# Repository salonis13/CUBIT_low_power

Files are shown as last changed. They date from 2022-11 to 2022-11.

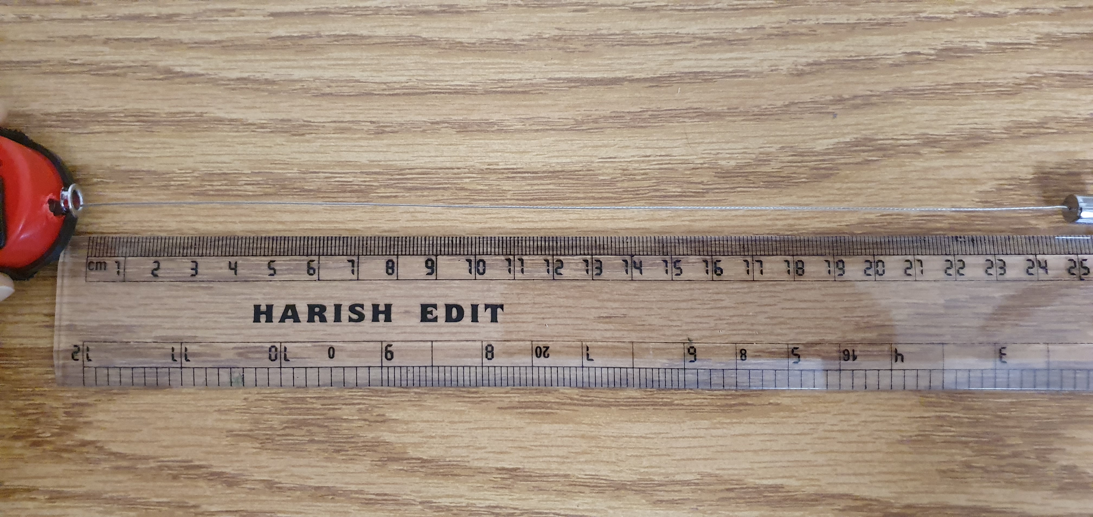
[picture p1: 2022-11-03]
images/Optical Rotary encoder 2.jpg

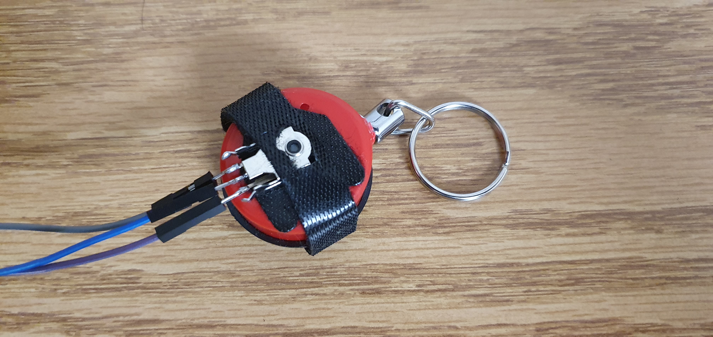
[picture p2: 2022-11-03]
images/Optical Rotary encoder 3.jpg

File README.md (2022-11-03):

# CUBIT
## ECEN5833 Low Power Embedded Firmware Development Project

Practically learn physical design techniques to develop a battery and energy harvested powered radio networked device for consumer, industrial, and high reliability applications. Through this project, we explored the engineering tradeoffs and made decisions on energy sources, energy storage devices, power supplies, radio networks, micro controllers, and sensors. Over the course of the semester, we went through design concept, design architecture, schematic entry, board layout design, PCB manufacturing, PCB assembly, test, debug, and verification.

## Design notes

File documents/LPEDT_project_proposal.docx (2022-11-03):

Project Proposal

ECEN 5833: Low Power Embedded Design Techniques

CUBIT

Smart Measuring Instrument

Team Name: Cubit

Team Members: Rajat Chaple

Saloni Shah

Background:

A measuring tape is used in a myriad of commercial businesses like construction, tailoring, warehouses as well as in day-to-day life. The first standard measuring tape was invented in 1850s and till now we have been using the same product. Although, since 18th century the world has advanced in every possible way, we still use the same measurement technique. The conventional measuring tape has ample of drawbacks like taking and maintaining measurements is very tedious, also all the measurements taken are majorly single use. It is high time that we modernize our method of taking measurements and digitize the data which can be easily stored and accessed from anywhere.

Project Summary:

For the course project, our team is designing a smart measuring instrument which will have the capability to take precise linear and angular measurements and transmit the data over to a mobile application using Bluetooth. Primarily, this device will have an encoder-wheel assembly which can be used to take measurements over a straight or curved surface very accurately. A high precision rotary encoder will be helpful in giving high resolution results. Moreover, we will also install an inertial measurement unit (IMU) sensor to take different angular and device orientation data. Both measurements can then be transmitted to a mobile app connected to the product using Bluetooth. This data will also be displayed on an LCD. This device will run on a small battery, and it will also contain an energy harvesting system using solar panel to recharge the battery. All these components will be interfaced with a single Blue Gecko board. The device will operate in low power mode by implementing load power management and utilizing minimum current for required peripherals.

108cm
0°

Measuring Tape

Wheel fixed on rotary encoder

LCD

Fig 1: Product Concept

Product Application:

- This product can be used to fulfill majority of measurement requirements like taking size data of a straight or uneven surface and taking angle measurements.
- This product can be used in small industries, construction sites, fashion companies and regular households.
- This product will eliminate the need to manually store measured data.
- This product will be low cost, low power consuming with energy harvesting mechanism.
- This product will use long lasting rechargeable batteries unlike single usage dry cells.

Block Diagram:

Micro-controller
Blue Gecko EFR32

IMU sensor

Rotary Encoder

Power Management

Battery

Solar panel-based charging

LCD Display

Product Components:

Component | | Part No. | Load Power Management
Microcontroller | Silicon Labs Blue Gecko
Radio | EFR32BG13 | | ✓
Battery | Lithium Ion/Lithium Polymer | TBD
Sensor | IMU sensor | BNO005 | ✓
| Rotary Encoder | TBD | ✓
HMI | LCD Display/Push buttons | TBD | ✓
Energy Harvesting System | Solar cells | TBD

Proposed Product Demo:

0cm
0°

Measuring Tape

36cm
0°

Measuring Tape

108cm
0°

Measuring Tape

As shown in the above image, this measuring tape can be used to measure any surface. The wheel encoder assembly installed on the product can be slid over a flat or uneven surface to get size value accurately. This measuring tape will have a high resolution in centimeter because of the use of a precision Rotary encoder with large number of pulse detection in a single rotation.

108cm
0°

Measuring Tape

108cm
30°

Measuring Tape

The above image shows how an angle measurement can be carried out using the product. This angle can be measured in any orientation of the device. The angle measurement will also be highly accurate due to the IMU sensor.

Product Features:

- Free android app to store and manage measurement data
- Bluetooth connectivity of mobile phone with the device
- Rotary encoder-wheel assembly for linear measurement
- IMU sensor for accurate angle measurement
- LCD Display for better user experience
- Energy harvesting mechanism using solar panels
- Load power management by turning on only required peripherals
- Single rechargeable LiPo battery which can power the complete device

Product Specifications:

- Dimensions: TBD
- Weight: TBD
- Wireless range: 100 m
- Size accuracy: ± 1 cm
- Angle accuracy: ± 1°
- Battery Life: TBD

Project Proposal

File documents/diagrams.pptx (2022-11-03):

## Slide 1

ESP 8266

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
MOSI

CS

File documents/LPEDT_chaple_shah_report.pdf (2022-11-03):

## ECEN 5833: Low Power Embedded Design Techniques

# CUBIT

# Smart Measuring Instrument

Team Name: | Cubit
Team Members: | Rajat Chaple
| Saloni Shah

Contents

Project Proposal

6.1.3 Actual Bulk capacitor value required (considering the DC bias)....55

7.1.1 | Testing of PWM output generation on Magnetic Encoder: | 59
7.1.2 | Frequency divider for Magnetic Encoder output: | 60
7.1.3 | Interfacing ultrasonic sensor with Blue Gecko development kit:..61
7.1.4 | Altium Board Layout: | 62
7.2 Activities planned for the upcoming week: | 63

Tables:
Table 1: Components List | 9
Table 2: Temperature specifications for sensors | 13
Table 3: Super cap - Battery comparison | 22
Table 4: Supercap and battery specifications | 22
Table 5: Voltage range for components | 23
Table 6: Components' library list | 29
Table 7: Timing Information | 32
Table 8: Battery specifications | 33
Table 9: Battery Tolerances | 33
Table 10: Project Schedule | 35

Project Proposal

## Project Proposal

## ECEN 5833: Low Power Embedded Design Techniques

# CUBIT

# Smart Measuring Instrument

Team Name: | Cubit
Team Members: | Rajat Chaple
| Saloni Shah

Project Proposal

# 1.1 Background

A measuring tape is used in a myriad of commercial businesses like construction, tailoring, warehouses as well as in day-to-day life. The first standard measuring tape was invented in 1850s and till now we have been using the same product. Although, since 18th century the world has advanced in every possible way, we still use the same measurement technique. The conventional measuring tape has ample of drawbacks like taking and maintaining measurements is very tedious, also all the measurements taken are majorly single use. It is high time that we modernize our method of taking measurements and digitize the data which can be easily stored and accessed from anywhere.

# 1.2 Project Summary

For the course project, our team is designing a smart measuring instrument which will have the capability to take precise linear and angular measurements and transmit the data over to a mobile application using Bluetooth. Primarily, this device will have an encoder-wheel assembly which can be used to take measurements over a straight or curved surface very accurately. A high precision rotary encoder will be helpful in giving high resolution results. Moreover, we will also install an inertial measurement unit (IMU) sensor to take different angular and device orientation data. Both measurements can then be transmitted to a mobile app connected to the product using Bluetooth. This data will also be displayed on an LCD. This device will run on a small battery, and it will also contain an energy harvesting system using solar panel to recharge the battery. All these components will be interfaced with a single Blue Gecko board. The device will operate in low power mode by implementing load power management and utilizing minimum current for required peripherals.

Project Proposal

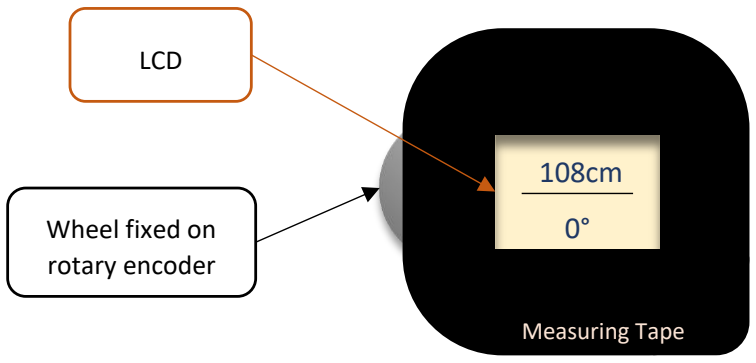
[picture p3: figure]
Measuring Tape; Wheel fixed on rotary encoder; LCD

Figure 1: Product Concept

# 1.3 Product Application

- This product can be used to fulfill majority of measurement requirements like taking size data of a straight or uneven surface and taking angle measurements.
- This product can be used in small industries, construction sites, fashion companies and regular households.
- This product will eliminate the need to manually store measured data.
- This product will be low cost, low power consuming with energy harvesting mechanism.
- This product will use long lasting rechargeable batteries unlike single usage dry cells.

Project Proposal

# 1.4 Block Diagram

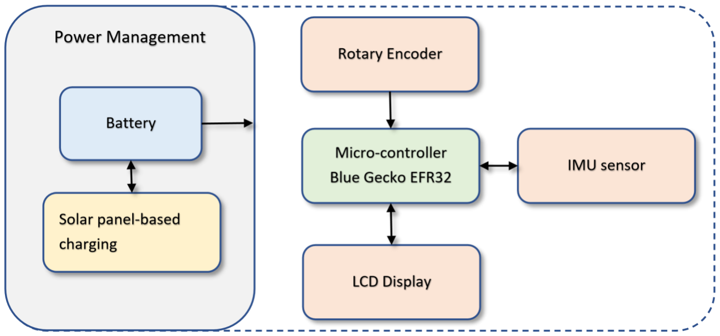
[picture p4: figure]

Figure 2: Block Diagram

# 1.5 Product Components

Table 1: Components List

Component | | Part No. | Load Power Management
Microcontroller | Silicon Labs Blue Gecko
Radio | EFR32BG13 | |
Battery | Lithium Ion/Lithium Polymer | LP802036JU+PCM+2 WIRES 50MM Jauch Quartz | Batte Products | DigiKey (https://www.digikey.com/en/products/detail/jauch-quartz/LP802036JU-PCM-2-WIRES-50MM/9560981)
PMIC | BQ25570 | BQ25570RGRT Texas Instruments | Integrated Circuits (ICs) | DigiKey (https://www.digikey.com/en/products/detail/texas-instruments/BQ25570RGRT/4430477)

Project Proposal

Buck Converter | TPS62842 Or PMIC internal buck converter | TPS62842DGRR Texas Instruments | Integrated Circuits (ICs) | DigiKey (https://www.digikey.com/en/products/detail/texas-instruments/TPS62842DGRR/12352343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)
Sensor | IMU sensor | BNO005 (To be acquired from Professor) |
| Rotary Encoder | Magnetic Rotary Encoder (https://www.digikey.com/en/products/detail/ams/AS5147P-TS-EK-AB/5452349) Magnetic Wheel Assembly (https://www.digikey.com/en/products/detail/ams/RMH05-DK-XX-1-0/3712276) |
| Ultrasonic Sensor | Adafruit Ultrasonic Sensor (https://www.digikey.com/en/products/detail/982/982-ND/5356850?itemSeq=389285645) |
HMI | LCD Display | Adafruit SHARP Memory Display Breakout - 1.3" (https://www.adafruit.com/product/3502) (Acquired from Professor) |
| Push Buttons | Available
Energy Harvesting System | Solar cells | Monocrystalline solar cells (https://www.digikey.com/en/products/detail/anysolar-ltd/KXOB25-12X1F-TB/9990434)

# 1.6 Proposed Product Demo

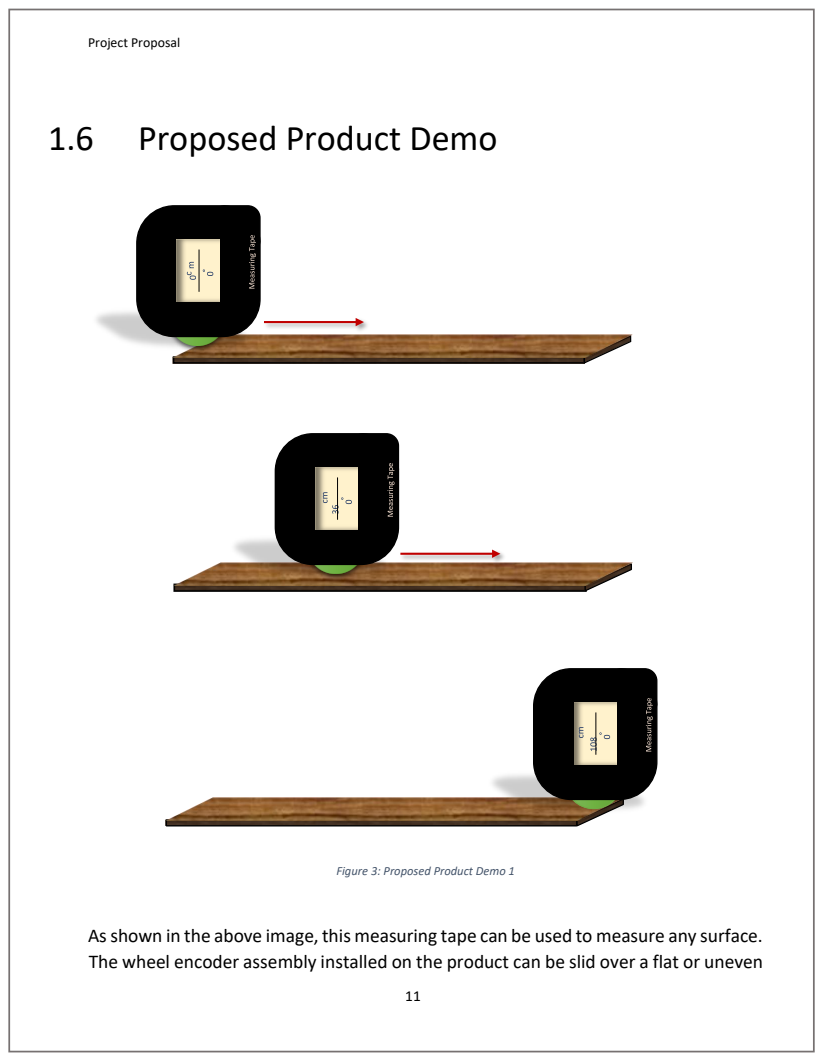
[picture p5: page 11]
Project Proposal

Figure 3: Proposed Product Demo 1

As shown in the above image, this measuring tape can be used to measure any surface.
The wheel encoder assembly installed on the product can be slid over a flat or uneven

Project Proposal

surface to get size value accurately. This measuring tape will have a high resolution in centimeter because of the use of a precision Rotary encoder with large number of pulse detection in a single rotation.

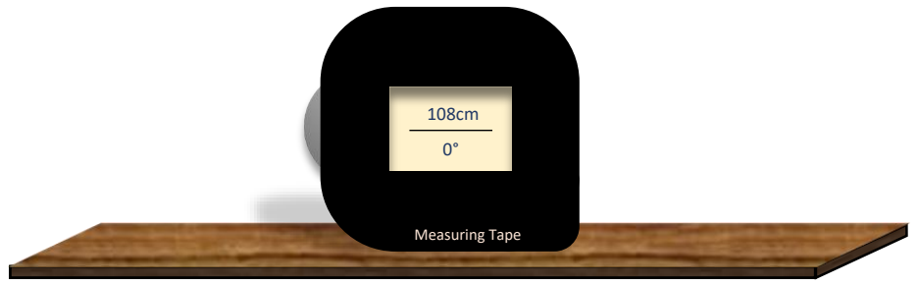
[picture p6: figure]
Measuring Tape
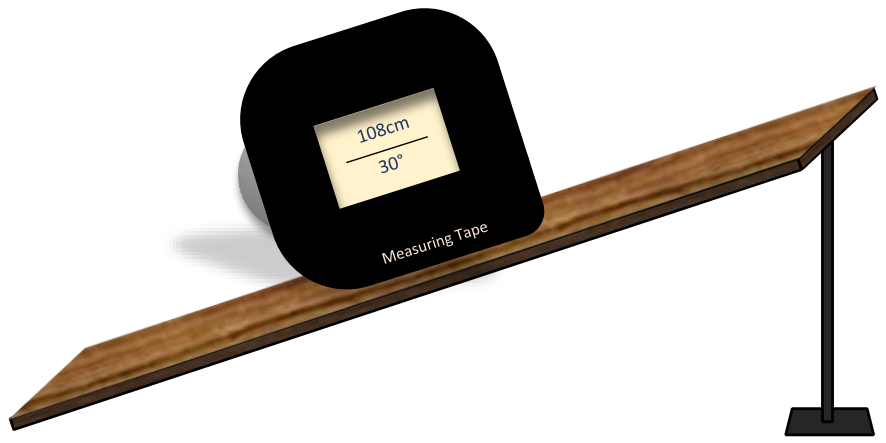
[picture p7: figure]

Figure 4: Proposed Product Demo 2

The above image shows how an angle measurement can be carried out using the product. This angle can be measured in any orientation of the device. The angle measurement will also be highly accurate due to the IMU sensor.

Project Proposal

# 1.7 Product Features

- Free android app to store and manage measurement data
- Bluetooth connectivity of mobile phone with the device
- Rotary encoder-wheel assembly for linear measurement
- IMU sensor for accurate angle measurement
- LCD Display for better user experience
- Energy harvesting mechanism using solar panels
- Load power management by turning on only required peripherals
- Single rechargeable LiPo battery which can power the complete device

# 1.8 Product Specifications

- Dimensions: 100mm x 70mm
- Weight: 100g
- Wireless range: 100 m
- Size accuracy: ± 1 cm
- Angle accuracy: ± 1°
- Product Warranty: 2 years
- Operating Temperature: 0°C - 65°C
- Internal sensors and peripheral operating temperature:

Table 2: Temperature specifications for sensors

Sensor | Operating Temperature Constraints
Blue Gecko | -40 to 85 °C
IMU | -40 to 85 °C
Rotary encoder | -40 to 150 °C
LCD Display | -40 to 70 °C

Project Update #2

## 2 Project Update 2 ECEN 5833: Low Power Embedded Design Techniques

# CUBIT

# Smart Measuring Instrument

Team Name: | Cubit
Team Members: | Rajat Chaple
| Saloni Shah
Date: | 01/29/2022

# 2.1Activities accomplished in past week

- Studied mouse scroll-wheel encoder assemblies to decide the decide the mechanical assembly for final product. Disassembled 4 different optical mouses to explore different assemblies.

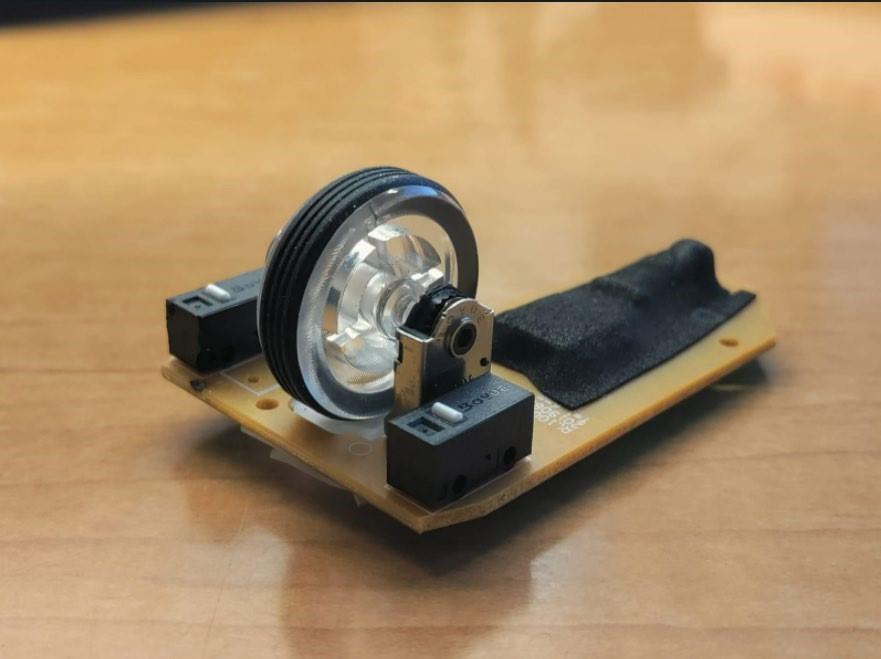
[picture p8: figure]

Figure 5: Scroll wheel encoder assembly

- Measured PPR(Pulse per rotation) of rotary encoder and circumference of wheel to estimate linear measurement resolution. o Finalized ultra-low power Graphic LCD display. o Estimated total power and energy consumption of the product.
- Worked on project planning and estimated timeline.
2.2 Activities for the coming week • Finalize battery and solar panel based on energy consumption requirements. o Finalize Power management IC. • Work on power supply circuit for the product.

# 2.3 Energy model for the product:

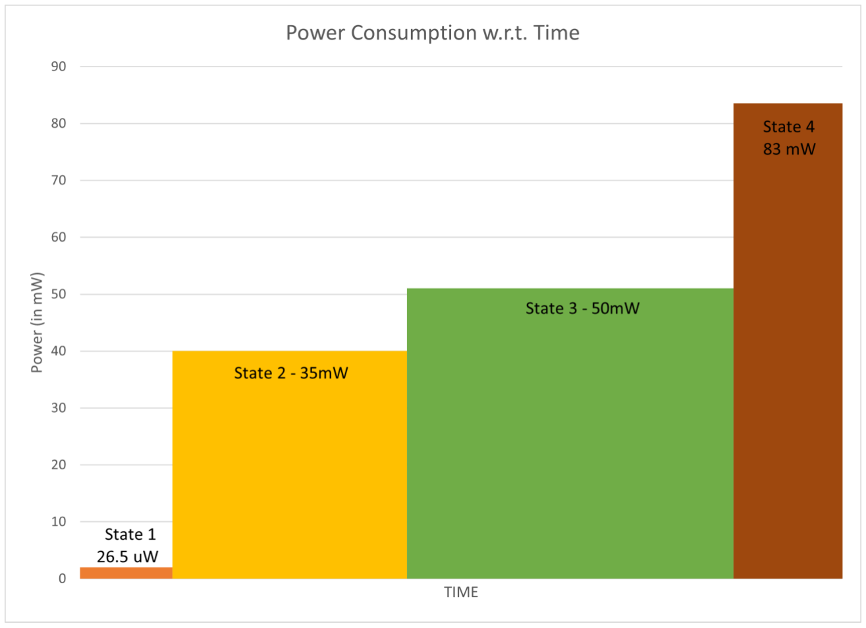
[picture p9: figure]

Figure 6: Energy model

# 2.4 Sensor selection:

### 2.4.1 IMU Sensor: BNO005

- This sensor works on I2C as well as UART.
- We will be interfacing the sensor using I2C as data transfer over UART communication takes longer and even though it consumes less energy, overall efficiency of UART decreases. Moreover, for transfer of larger data bytes I2C consumes the same amount of energy. (These assumptions were made using this reference. (http://cc.oulu.fi/~kmikhayl/site-assets/pdfs/2012_NTMS.pdf)) (http://cc.oulu.fi/~kmikhayl/site-assets/pdfs/2012_NTMS.pdf)
- This sensor will require external load switch as after start-up it only enters low power mode and suspend mode. (Even in suspend mode it consumes 40uA of current).

### 2.4.2 Rotary encoder

- This mechanical encoder has just 2 digital pins which can be wired directly as input to the controller. The encoder generated pulses gives the angular position of the axis and can then be converted to digital output.
- The encoder will also require external load switch as it does not have internal circuitry to turn power off.

Online Project Management using Monday.com (https://view.monday.com/2210043877-dee7e4668b7b619c0c4a18486899a087?r=use1)

# 2.5 Program Flowchart:

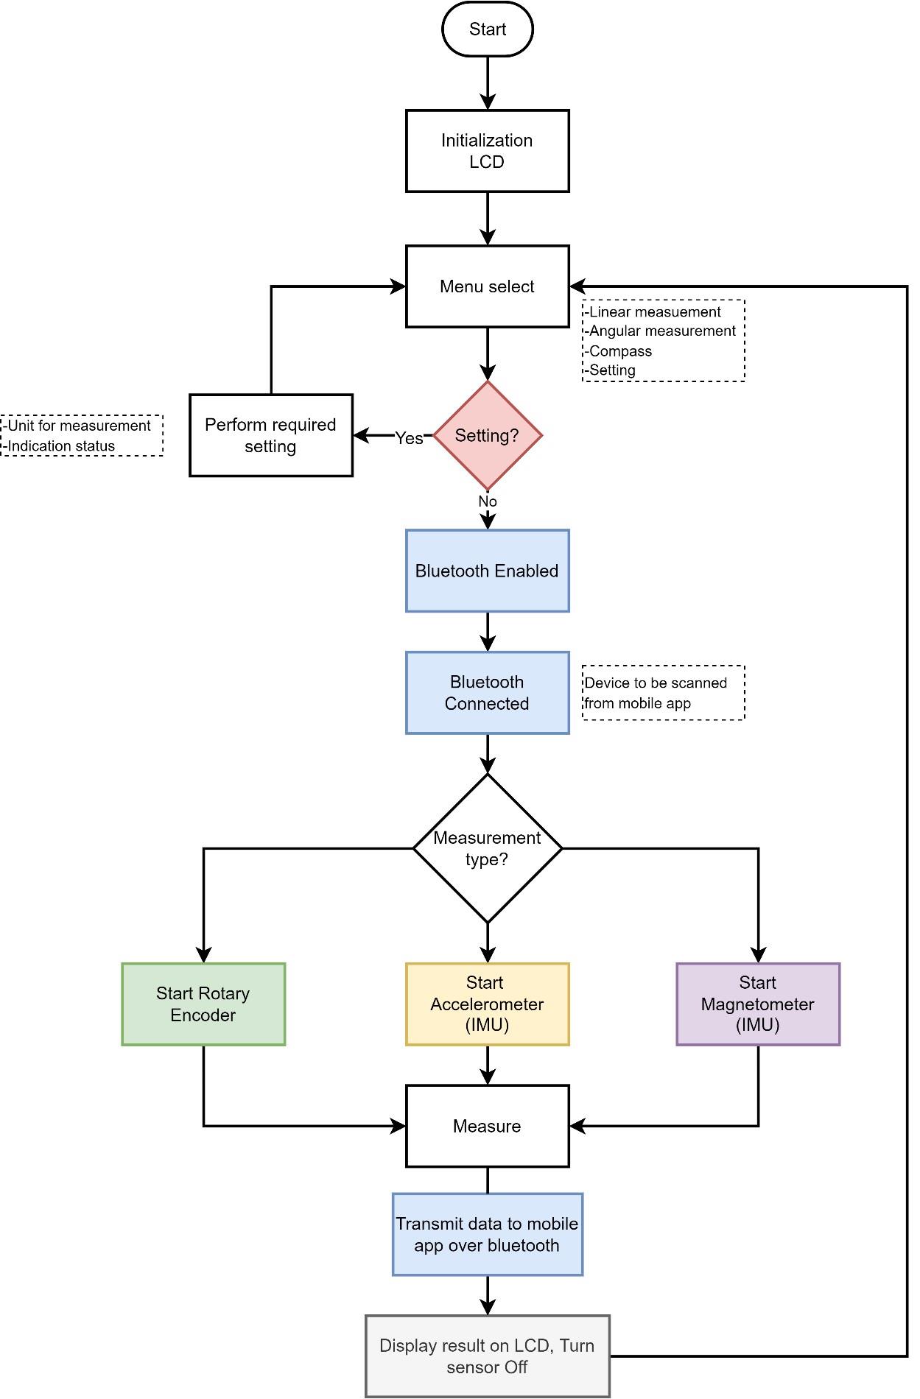
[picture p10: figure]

Figure 7: Flowchart

## 3 Project Update 3 ECEN 5833: Low Power Embedded Design Techniques

# CUBIT

# Smart Measuring Instrument

Team Name: | Cubit
Team Members: | Rajat Chaple
| Saloni Shah
Date: | 02/05/2022

# 3.1 Activities accomplished in past week:

- Finalized energy storage element (battery) based on energy consumption requirements.
- Finalized Power management IC and buck-converter IC.
- Practically implemented measurement system using mechanical rotary encoder, string-pulley assembly and interfaced it with Arduino. Found out that the rotary encoders have a limitation on how fast it can detect rotations i.e. it can only detect signals correctly at less than 160 rpm.

Figure 8: Assembled rotary encoder with a string-pulley

Figure 9: Measuring the length of a ruler using the assembly

Arduino serial monitor output with number of pulse counts and calculated length

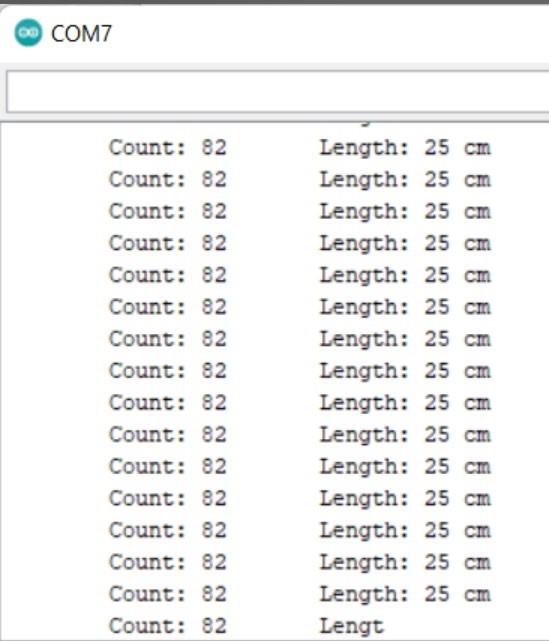
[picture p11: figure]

Figure 10: Optical Rotary Encoder output

- Changed the required rotary encoder from mechanical to magnetic due to speed constraints and higher chances of signal misses in the mechanical encoder.
- Finalized required magnetic rotary encoder and ultrasonic sensor for measurement applications.

# 3.2 Activities for the coming week

- Finalized energy harvesting element (solar panel) based on energy consumption requirements.
- Design product power supply circuit.
- Interface LCD display with Blue Gecko Evaluation Module.
- Finalize other required components for the product schematic design.

Power Storage Element Selection
- Expected runtime using supercapacitor = 1.36 hours
- Expected runtime using battery = 3 days (8 hours per day)¹

### 3.2.1 Super Cap vs Battery

Required peak current: 25 mA
Average current consumption: 13.68 mA
Average Charge requirement for continuous 8 hours operation: 110mAh Average Energy Required for 8 hours of operation: 328.4 uWh
Ambient Temperature Conditions: Room Temperature (about 25° C)

Table 3: Super cap - Battery comparison

Super Cap | Battery
Steep discharge curve | Higher operating time
Large leakage current (30 uA) | Very less leakage current (2%/year)
Cannot handle required peak current | Can handle upto 1A peak current
Lower energy density | Higher energy density
Can operate in very low temperature | Dispenses less energy in low temperatures
Lower ESR power loss | Higher ESR power loss

Table 4: Supercap and battery specifications

Design Requirements | Super Cap (Tecate 100F) | Battery (Jauch 480mAh)
Useable Energy | 234.5J² - 18.6mAh | 480 mAh
Peak Discharge Current | | 1A
Recharge time | | 2 hours @ 0.5C
2 years of use, 300 charges | 500,000 cycles | 300 cycles ~ 80% capacity usage
Leakage current or rate | 3 uA | Less than 2-3%
ESR | 210 mΩ
Mechanical Dimensions | 12.5 x 25 mm | 38 x 20.5 mm

1 Refer attached spreadsheet for calculations 2 Refer attached spreadsheet

# 3.3 Power Management Unit Selection

### 3.3.1 Determining the required voltage range for the product

- To decide the operating voltage range for the product, we looked at the input voltage range of the peripherals utilized in the system. The below table shows the minimum and maximum input voltage range of the sensors and MCU.

Table 5: Voltage range for components¹

Sensor | Vin(min) | Vin(max) | Current Consumption
Blue Gecko | 1.8V | 3.8V | 4uA
IMU | 2.4V | 3.6V | 12.3mA
Rotary encoder | 3V | 3.6V | 15mA
LCD Display | 3V | 5V | 4uA
- Based on the above calculations, we decided to operate all the peripherals at 3.0V as to utilize maximum possible battery capacity and increase the operating time of the system.
- The approximate range of the supply voltage will be from 3.0-3.6V.

1
IMU datasheet: BNO055 Datasheet (mouser.com) (https://www.mouser.com/datasheet/2/783/BST_BNO055_DS000-1509603.pdf)
Blue Gecko datasheet: (https://www.silabs.com/documents/public/data-sheets/efr32bg13-datasheet.pdf) EFR32BG13 Data Sheet: Blue Gecko Bluetooth® Low Energy SoC Family (silabs.com) (https://www.silabs.com/documents/public/data-sheets/efr32bg13-datasheet.pdf)
Magnetic Rotary Encoder datasheet: (https://www.digikey.com/en/products/detail/ams/AS5147P-TS-EK-AB/5452349) AS5147P-TS_EK_AB ams | Development Boards, Kits, Programmers | DigiKey (https://www.digikey.com/en/products/detail/ams/AS5147P-TS-EK-AB/5452349) LCD (https://www.digikey.com/en/products/detail/ams/AS5147P-TS-EK-AB/5452349)
Display datasheet: (https://cdn-shop.adafruit.com/product-files/3502/Data+sheet.pdf) Data+sheet.pdf (adafruit.com) (https://cdn-shop.adafruit.com/product-files/3502/Data+sheet.pdf)

### 3.3.2 Determining the power management topology

- Considering that the power source battery gives maximum 3.7V and our required voltage supply for the peripherals is about 3.0V, which is always lower than supply voltage we decided to implement a buck converter to meet our power requirements.
- The primary reason for choosing a buck converter as opposed to a buck-boost is that most Lithium-Poly batteries have a plateau from 3.5-3.6V and very little charge below this plateau, limiting the usefulness of the buck-boost converter and its wide input voltage range2.
- Moreover, the buck-boost converter also has one additional MOSFET as compared to the buck converter which increases power loss and decreases efficiency of the converter.
- Keeping this in mind, we searched for a buck converter IC, with high efficiency, low quiescent current, low cost, and smaller footprint.
- All these requirements were successfully met by the buck converter TPS62840³

### 3.3.3 Determining Regulated or Unregulated Power Source

- While deciding whether to use regulated or unregulated power source, we carried out following calculations to understand efficiency of both topologies.

Assumed product usage of 60 minutes or 3600 seconds

Assumed number of measurements in 1 hour, average of 20 measurements

Assumed period for one measurement, average of 13 seconds

On duty cycle = (20 measurements * 13 seconds) / 3600 = 7.2% Off

duty cycle = 92.8%

2 EETimes - Buck-boost vs. buck converter: it's about battery life in portables (https://www.eetimes.com/buck-boost-vs-buck-converter-its-about-battery-life-in-portables/)
3 TPS62840 datasheet: (https://www.ti.com/lit/ds/symlink/tps62840.pdf?HQS=dis-dk-null-digikeymode-dsf-pf-null-wwe&ts=1644076764086) TPS62840 1.8-V to 6.5-V, 750-mA, 60-nA IQ Step-Down Converter datasheet (Rev. D) (ti.com) (https://www.ti.com/lit/ds/symlink/tps62840.pdf?HQS=dis-dk-null-digikeymode-dsf-pf-null-wwe&ts=1644076764086)

TPS62840 Buck converter Efficiency Curve

- Off duty cycle = 0.015-0.020 mA Estimated 87.5% efficiency
- On duty cycle = 15-20 mA range Estimated 94% efficiency

For regulated power case (using TPS62840 buck converter):

- On duty cycle
- TPS62840 efficiency ~3.6V input and 15,500uA is 94% + 0.06uA Iccq
- Weighted avg power OOB = (On duty cycle * (15500 + 0.06) * 3.0V) / 94%
- Weighted average power out of battery = 3561 uW o Off duty cycle
- TPS62840 efficiency ~3.6V input and 20uA is 87.5% + 0.06uA Iccq

- Weighted avg power OOB = (Off duty cycle * (20 + 0.06) * 3.0V) / 87.5%
- Weighted average power out of battery = 63.8 uW o Total Average Power out
- Weighted on duty cycle average power + Weighted off duty cycle average power = 3561uW + 63.8uW = 3624.825 uW

For unregulated power case (using Blue Gecko internal LDO):

- On duty cycle
- Gecko efficiency ~3.6V input and 15,500uA is 83.33%
- Weighted average power OOB = (On duty cycle * 15500 * 3.0V) / 83.33%
- Weighted average power out of battery = 4017.7 uW o Off duty cycle
- Gecko efficiency ~3.6V input and 20uA is 83.33%
- Weighted average power OOB = (Off duty cycle * 20 * 3.0V) / 83.33%
- Weighted average power out of battery = 66.81 uW o Total Average Power out
- Weighted on duty cycle average power + Weighted off duty cycle average power = 4017.7uW + 66.81uW = 4084.5 uW

Increase in battery life using regulated power = 1 -

= 11.25%

Based on above calculations, we decided to use a regulated power source since it provides longer battery life. Moreover, we have a higher on duty cycle, higher power on to power off ratio, higher efficiency at light load and low quiescent current which justifies the use of regulated power source.

### 3.4. Determining the Power Management IC

- The primary criteria for selecting a PMIC were low minimum input voltage limit to support very low voltage from energy harvesting element (solar cell) and efficient boost converter. A simple and efficient circuitry for energy harvester is required which were available in PMIC BQ25570.

- The input voltage supported in this IC is 0.1-5.1V. Also, many typical solar cells have an output voltage of 0.1V.
- Another important criterion is to have a wide range of input voltage from battery to support lower battery power which is 2-5.5V in case of BQ25570.
- This IC also has higher charging current capacity (maximum 285mA) for fast charging from external charger or a USB charging port.
- BQ25570 also has internal Programmable Maximum Power Point Tracking (MPPT) circuitry for optimal energy extraction from energy harvester like solar panel.
- Moreover, BQ25570 has internal boost as well as buck converter to boost low input voltage from the energy harvester and simultaneously regulate the output voltage⁴

4 BQ25570 internal buck converter vs external TPS62840 buck converter: The TPS62840 buck converter has higher efficiency at low current consumption than the internal buck converter.

## 4 Project Update 4 ECEN 5833: Low Power Embedded Design Techniques

# CUBIT

# Smart Measuring Instrument

Team Name: | Cubit
Team Members: | Rajat Chaple
| Saloni Shah
Date: | 02/12/2022

# 4.1Activities accomplished in past week:

- Generated Altium components library for following parts

Table 6: Components' library list

Sr. No | Part Description | Part Number | Footprint Name | Online SnapEDA/ Octopart Link
1 | Blue Gecko | EFR32BG13P732F512GM48-D | 48-QFN_7x7 | N/A
2 | PMIC | BQ25570RGRT | 21_QFN_35X35 | N/A
3 | IMU Sensor | BNO055 | LGA28R50P4X10_380X520X100 | BNO055 SnapEDA (https://www.snapeda.com/parts/BNO055/Bosch%20Sensortec/view-part/)
4 | Magnetic Encoder | AS5147P-HTSM | 14-TSOP_5x4_4 | N/A
5 | Resistor | RMCF0603FT1K00 | 2_Chip_0603_RMCF | N/A
6 | Capacitor | CL10A475KP8NNNC | CAP_0603_1MM | N/A
7 | Inductor | VLS3015CX-220M-1 | 2_IND_3x3 | N/A
8 | LED (red) | 150060RS75000 | LED_0603_RED_WL-SMCW | N/A
9 | LCD header | 3502 | LCD_SHARP_MEMORY_9_PIN | N/A

### 4.1.1 Change in the Power management strategy

- With earlier update, plan was to use PMIC bq25570 and TPS62842 buck converter. Criterion for selection of external buck converter instead of one already integrated into bq25570 was Efficiency. However, considering ON duty cycle of the product operation, efficiency would no longer be a preliminary factor under consideration.
- Also, major concern where we cannot utilize most energy from the battery was resolved using following.
- Entire circuit would work at 3.15v
- Buck converters have dropout voltage. This limits battery’s minimum usable voltage. As per datasheet, dropout voltage is maximum output current times the buck high side resistance.

- Usable battery would be in the range of 3.7v down to 3.22v.

### 4.1.2 Tested battery power consumption from a sample project

- As a case study one of the sample projects was arranged. Though this project’s objective is entirely different than that of CUBIT, similarities in functional blocks were identified. This project also contains solar energy harvesting, PMIC and a load.

Figure 11: Sample Product for case study

Calculations:
Maximum output current: 35 mA Maximum buck high side resistance: 200Ω

Dropout voltage: 35 x 200 = 0.7v

Energy
Harvesting unit

Load
(Power LED)

Battery
(300 mAh)

### Sample Project Block Diagram

Calculations:

Continuous current consumption by Power LED = 55 mA

Tℎeoretical battery backup =

Battery capacityሺmAℎሻ
Continuous current consumption

=

500
55 = 9.09 Hrs

Objective: Solar power lamp
Battery capacity = 500mAh
No of Solar cells = 7 (part number unknown)
LEDs: 1 power LED of typical current consumption of 50mA
Solar Panel | Microcontroller | LED Driver
Battery | LED

Practically measured battery backup: 9 hours
If current consumption was 18mA, we would get battery backup of ~27 Hrs

Outcome of the experiment:
Our calculation for CUBIT falls between this range where battery backup for 480 mh battery with 18mA avg current consumption is around 24 Hrs. This verifies calculations against practical measurements.

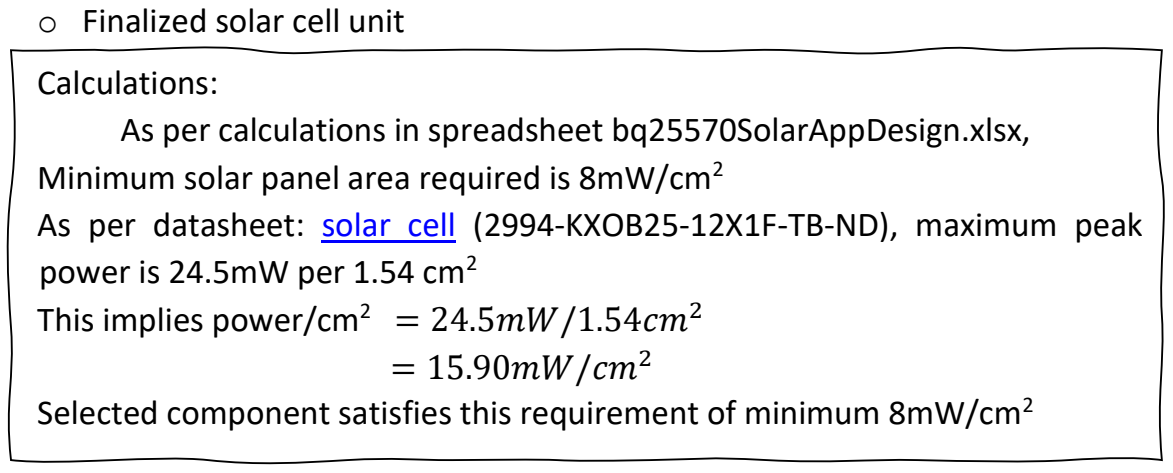
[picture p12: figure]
• Finalized solar cell unit; Calculations:; power is 24.5mW per 1.54 cm² This implies power/cm²; = 24.5mW/1.54cm² = 15.90mW/cm²

### 4.1.3 Version tracking using GitHub

Updated previous updates, libraries and calculation documents to github rajatchaple/ecen5833_s22_lpedt_project (github.com) (https://github.com/rajatchaple/ecen5833_s22_lpedt_project)

### 4.1.4 Timing information

Following are the critical timing parameters per module.

Table 7: Timing Information
Device | Parameter | Description | Min | Max
AS5147 (SPI) | tL | Time between CSn falling edge and CLK rising edge | 350 ns
| tH | Time between last falling edge of CLK and rising edge of CSn | 50 ns
| tMOSI | Data input valid to falling clock edge
BNO055 | fSCL | Clock frequency | | 400kHz
| fSUDAT | SDA Setup Time | 0.1 us
| HDDAT | SDA Hold TIme | 0 us
SHARP Memory LCD | fSCLK | Clock Frequency | | 1.1MHz
| tsSCS | SCS Setup time | 6 us
| thSCS | SCS hold time | 2 us
| tsSI | SI setup time | 250 ns
| thSI | SI hold time | 350 ns

As per calculations in spreadsheet bq25570SolarAppDesign.xlsx, Minimum solar panel area required is 8mW/cm²
As per datasheet: solar cell (https://waf-e.dubudisk.com/anysolar.dubuplus.com/techsupport@anysolar.biz/O18Adzn/DubuDisk/www/Gen2/KXOB25-12X1F%20DATA%20SHEET%20202007.pdf) (2994-KXOB25-12X1F-TB-ND), maximum peak

Selected component satisfies this requirement of minimum 8mW/cm²

### 4.1.5 Calculations for PMIC IC

- Studied reference design in bq25570 user guide (https://www.ti.com/lit/ug/sluuaa7a/sluuaa7a.pdf?ts=1644694996855) in order to understand PMIC circuitry for our application.
- Also, used calculator provided by TI on BQ25570 data sheet, product
information and support | TI.com (https://www.ti.com/product/BQ25570#design-tools-simulation) to calculate Resistor values.

### 4.1.6 Battery specifications

Table 8: Battery specifications
Parameter | Value
Battery nominal Voltage | 3.7V
Typical capacity | 500mAh
Minimum capacity | 480mAh
Charge voltage | 4.2V
Standard current | 0.2C-100 mA
Max charging current | 0.5C – 250mA
Cut-off voltage | 3V
Max discharging current | 2C-1A
Power rating | 1.78Wh

Battery Tolerances

Table 9: Battery Tolerances
Parameter | Value
Overcharge voltage | 4.28 V ± 0.025 V
Overdischarge voltage | 3.00 V ± 0.05 V
Over current range | 1.0A to 4.0A
Charging operating temperature | +10°C to +45°C
Discharging operating temperature | -20°C to +25°C

### 4.1.7 High risk elements:

- Magnetic interference of two sensors
- IMU has a magnetometer which is to be used for compass and the rotary encoder is also based on magnetic pulse. These two components can interfere with each other and show incorrect reading. As a measure to mitigate this risk, we will be placing the two components physically as far as possible from each other on the board.
- EMI interference
- Similar to the issue mentioned, the magnetic field from these components can also generate electromagnetic interference which can disrupt the functionality of other components on the board especially inverted F-antenna for Bluetooth connection (radio frequency can be disrupted due to electromagnetic interference). The potential solutions to overcome EMI are filtering, shielding, or grounding.
- Dual charging system (USB and Solar cell)
- As a power storage component, we are using a rechargeable LiPo battery. To recharge this battery, we are planning on using energy harvesting component - solar cells. Apart from the solar cells, we also intend to have a 5V USB charging port on the board.
- The major drawback in this design is the unavailability of a power management IC to efficiently switch between solar cells and USB port. Even if we interface a USB port, we have to have a circuit design such that reverse current does not flow from battery to our energy harvesting device and also to automatically switch between solar energy and USB input.
- In this circuit design, we plan to use Schottky diodes for fast switching and low voltage drop. In case we are unable to successfully implement this design, we will be eliminating use of USB charging port and use the solar power as our primary recharge source.

### 4.1.8 Project Schedule:

Table 10: Project Schedule
Task | Deadline
Altium Components Libraries | Feb 12, 2022
Altium Product Schematic | Feb 26, 2022
Altium Product Layout | March 5, 2022
Product Final Layout for Fabrication | March 12, 2022
Send PCCB board for fabrication | March 19, 2022

We are aligned with our project timelines except the task where our plan was to bring up LCD module last week. We will be achieving this task in upcoming week. Instead, this week we focused on our case study of sample project to verify our energy calculations.

# 4.2 Activities planned for the upcoming week:

- Finalizing Bulk capacitance
- Implement LCD driver
- Schematic of Power Management Unit

## 5 Project Update 5 ECEN 5833: Low Power Embedded Design Techniques

# CUBIT

# Smart Measuring Instrument

Team Name: | Cubit
Team Members: | Saloni Shah
| Rajat Chaple
Date: | 02/18/2022

# 5.1Activities accomplished in past week:

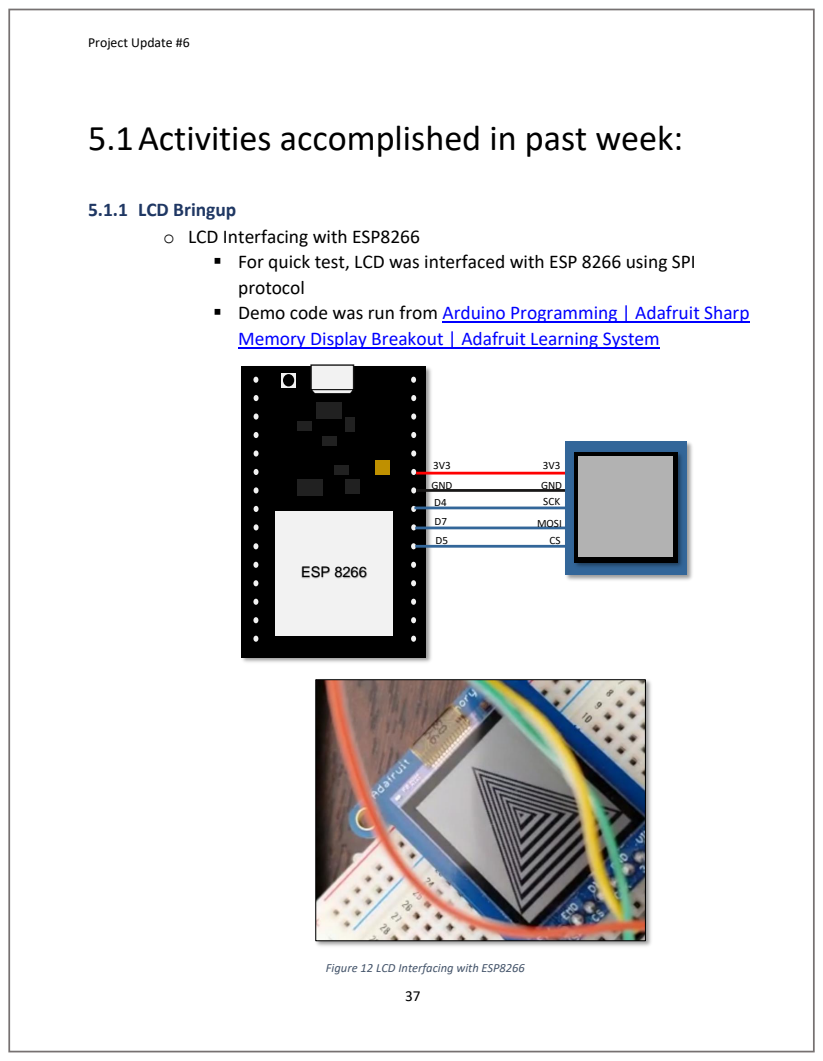
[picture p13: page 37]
5.1.1 LCD Bringup; ESP 8266; GND; SCK; MOSI

• LCD Interfacing with ESP8266
▪ For quick test, LCD was interfaced with ESP 8266 using SPI
protocol
▪ Demo code was run from Arduino Programming | Adafruit Sharp
Memory Display Breakout | Adafruit Learning System (https://learn.adafruit.com/adafruit-sharp-memory-display-breakout/programming)

Figure 12 LCD Interfacing with ESP8266

- LCD Interfacing with Blue Gecko
- Connections

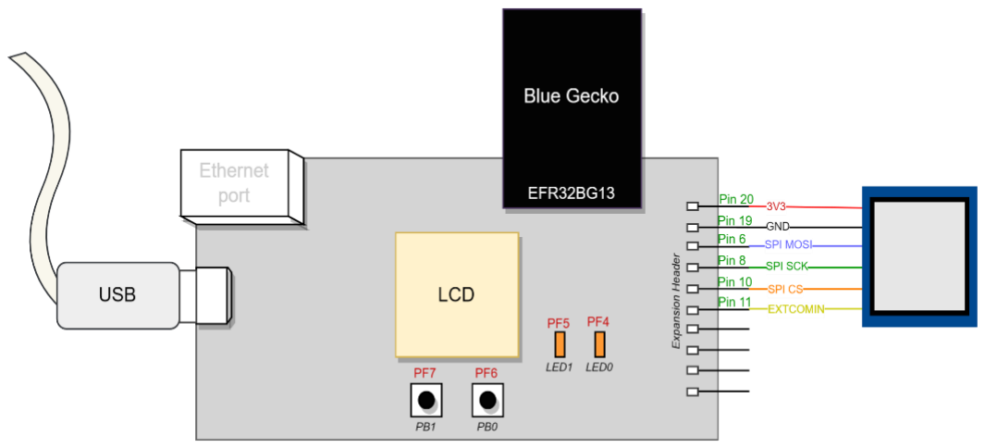
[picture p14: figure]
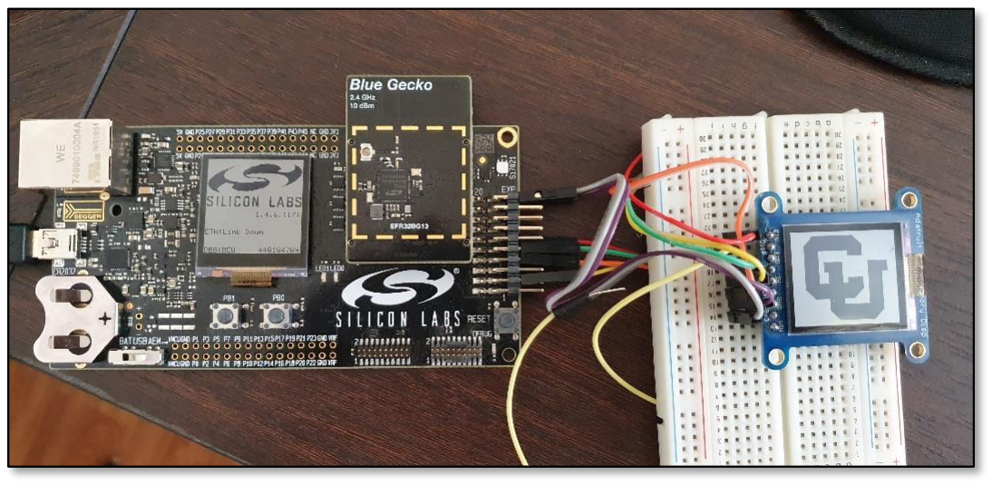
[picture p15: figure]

Figure 13 LCD Interfacing with Blue Gecko

- Python Script for Image to binary
- LCD requires array in binary format representing the graphics
- Python script was written to convert any image into 168x144 graphics.
- CU Logo was generated using this script.

- Findings

Figure 14 Current consumption by LCD
- Current consumed by LCD is around 100uA
- Getting rid of additional components from the module

Figure 15 LCD without a breakout module circuit
Current consumption did not change even after removing these additional components

LCD connected:
Current (240 uA) | LCD detached:
| Current (141 uA)

Removed Regulator and Logic level shifter

### 5.1.2 PMIC Simulation and Bulk capacitance

- In order to simulate Power management unit in LTSpice, we did not find the exact part number
- Combination of boost circuitry and LT8604 was used to simulate as these parts were matching with bq25570 specs.

Figure 16 Calculating Bulk capacitor value

Below simulation showed that there is need of 100uF bulk capacitor.

Addition of bulk capacitor restricts minimum voltage of the system at 3.15v. This satisfies requirements for all peripherals and the controller.

# 5.2Activities planned for the upcoming week:

- Designing a schematic of Power Management unit and sensor interfacing
- Implement IMU sensor driver

# 5.3Miscellaneous:

1. What features, components, will need to be added to your schematic to enable programming of your micro controller or SoC?
a. 10 pin Debug connector would be added to the board schematic

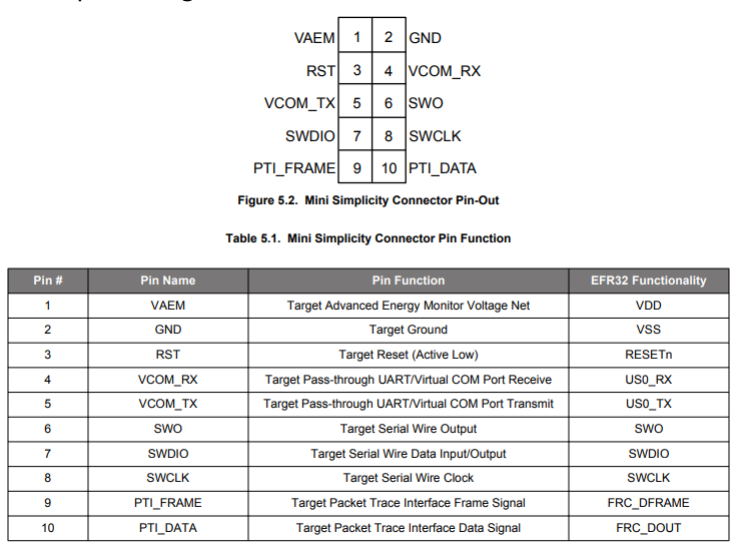
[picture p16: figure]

Figure 17 Debug connector pinout

Source: AN958: Debugging and Programming Interfaces for Custom Designs (silabs.com) (https://www.silabs.com/documents/public/application-notes/an958-mcu-stk-wstk-guide.pdf)

Following features would be available with this debug port:
1) SWD (Serial Wire Debug)
2) AEM (Advanced Energy Monitoring)
3) PTI (Packet trace interface)
4) VCOM (Virtual COM port)
5) Virtual UART

The Debug In mode of the debugging would be used

Figure 18 Debug interface with Radio board

Source: UG279: EFR32BG13 Blue Gecko Bluetooth Starter Kit User's Guide (silabs.com) (https://www.silabs.com/documents/public/user-guides/ug279-brd4104a-user-guide.pdf)

2. Describe the process of how you will compile and download code to your board, the target board
1) Simplicity studio v5 would be used as a programming IDE during development.
a. GNU ARM C compiler (cross compiler: arm-none-eabi-gcc) would be used to compile the code
b. Simplicity Studio v5 also provides an option to select your development board. This in turn defines the memory map of the controller.
2) Simplicity Commander would be used to download the code into target board Command line syntax: commander [command] [options] [arguments] Sequence of commands would be,
a. Erase Flash
b. Flash new code
c. Verify written data
d. Reset the microcontroller

3. Which signals will have test points?
a. SPI port (For LCD and Magnetic Rotary Encoder)
- SCLK
- CS
- MOSI
b. I2C port (for IMU Sensor)
- SCL
- SDA
c. UART pins (for Ultrasonic sensor)
- RX/TX
d. Power pins of each sensor
e. PMIC Vout
f. Energy Harvester Input
g. USB Input
h. Battery Storage input
4. Reset Circuit Description
Reset would be controlled by 2 modes of operation
a. Reset via Debugging Interface
- Pin 3 on Mini debug connector
b. On board reset switch
- Pin 12 on EFR32BG13 is nReset
- Active low
- It’s only required to drive this pin low externally
- Internal pull-up pulls this pin high

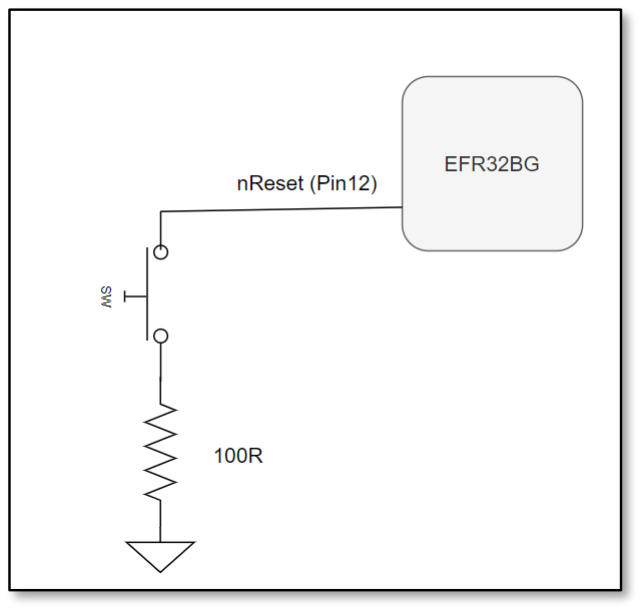
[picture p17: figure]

Figure 19 Reset circuit
5. Clock Generation Description
a. Both oscillators Low Frequency and High Frequency oscillators would be required:
- High Frequency crystal (38 to 40 MHz): For Radio
- Low Frequency crystal (32.768 kHz): For Low Energy modes operation
b. There are also other oscillators available for clock generation namely
1) High Frequency RC oscillator
2) Auxiliary high frequency RC oscillator
3) Precision LF RC oscillator
4) Low frequency RC oscillator
5) Ultra-low frequency RC oscillator

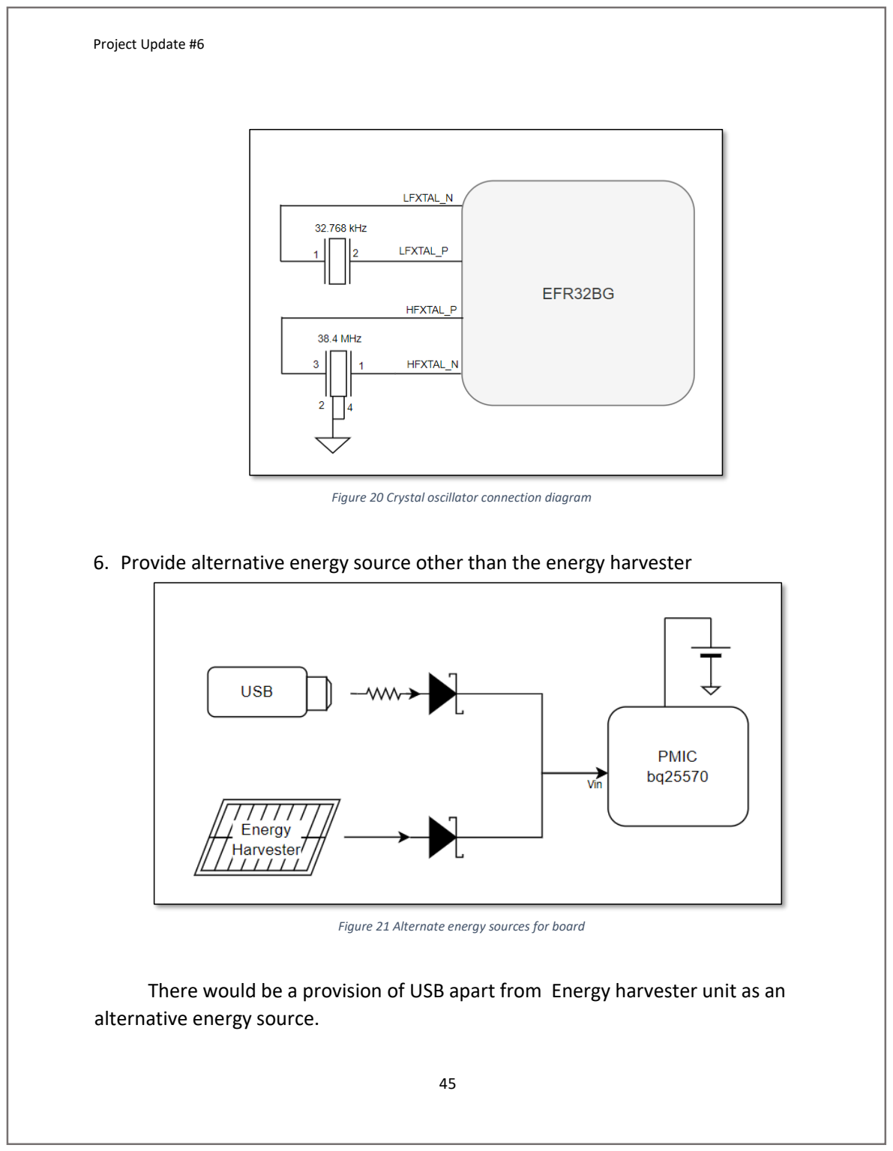
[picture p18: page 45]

Figure 20 Crystal oscillator connection diagram

6. Provide alternative energy source other than the energy harvester

Figure 21 Alternate energy sources for board

There would be a provision of USB apart from Energy harvester unit as an alternative energy source.

- Schottky diodes would be used to allow both the energy sources to be connected at the same time.
- As VIN_DC is ppulled to ground through a small resistance, USB supply would have a resistance in series to limit the current flow. This solves below problem,
7. Jump Start method to charge the energy storage element in the event that the Energy Harvester circuity is not functional or takes too long.
- Along with above circuit, there would be a provision to disconnect the battery from the embedded device and charge it using Lab power supply.
- Battery would be charged at 235mA as 250 mA is the maximum charging current for the battery. Charge voltage would be set to 4.2V

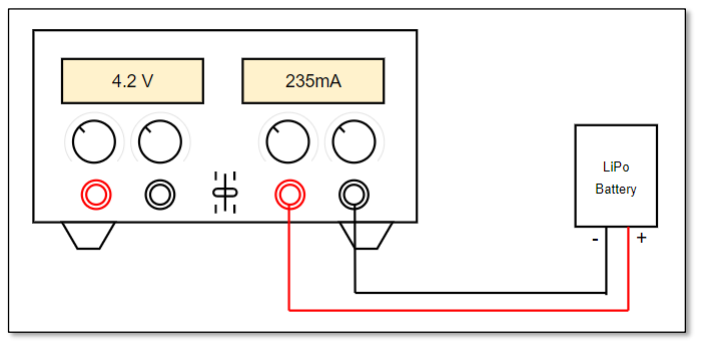
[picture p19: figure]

Figure 22 Battery charging using power supply

8. What is the maximum charging current allowed by the PMU circuitry? As per PMIC datasheet,
- Typical charging current is 235mA and
- Maximum charging current allowed by PMU is 285mA
9. What is the maximum charging current allowed by the energy storage unit specs?
- Max charge current for the battery (https://www.jauch.com/downloadfile/5bf529c4ea71fa4bbc13432e4fc07e5a8/480mah_-_lp802036ju_1s1p_2_wire_50mm.pdf) is 0.5C i.e. 250mA
10. What will the maximum current of the jump start power source be set to?
- Maximum current for the jump start can be set to 250mA as supported by the battery.
11. Where will the jump start power and ground signals connect to? Following are the two options for the jump start,
1) Disconnect battery and charge it using Lab power supply
2) Charge battery using USB via PMIC
12. Ensuring that there is enough energy / current to program the flash of the MCU how much current will the programming of the MCU flash require?
As per datasheet,
- Current consumption during flash write is 3.5 mA and
- Current consumption during Flash read is 2.0 mA

Figure 23 Flash memory specs

13. How much current will the energy storage element and the PMU be able to provide?
Unit | Current
Energy storage element (Battery) | 1 A (2C)
PMU (bq25570) | 110 mA
14. What are the connection points to enable external power to digital / MCU portion of the board?
- USB as an input to the PMIC would be used to power digital/MCU portion of the board.
- External lab power supply would be used to charge the battery.

## 6 Project Update 6 ECEN 5833: Low Power Embedded Design Techniques

# CUBIT

# Smart Measuring Instrument

Team Name: | Cubit
Team Members: | Saloni Shah
| Rajat Chaple
Date: | 02/25/2022

# 6.1Activities accomplished in past week:

### 6.1.1 IMU Bring-up

- BNO055 interface with Blue Gecko
- IMU Communicates with EFR32 radio board over I2C protocol.
- BNO055 supports two configurable addresses, 0x29 and 0x28. 0x28 address was selected for the communication.
- For bring-up, accelerometer values were read. This required following configuration
- Set up config bits of IMU to turn on Accelerometer
- Read lower byte of accelerometer
- Connection Diagram

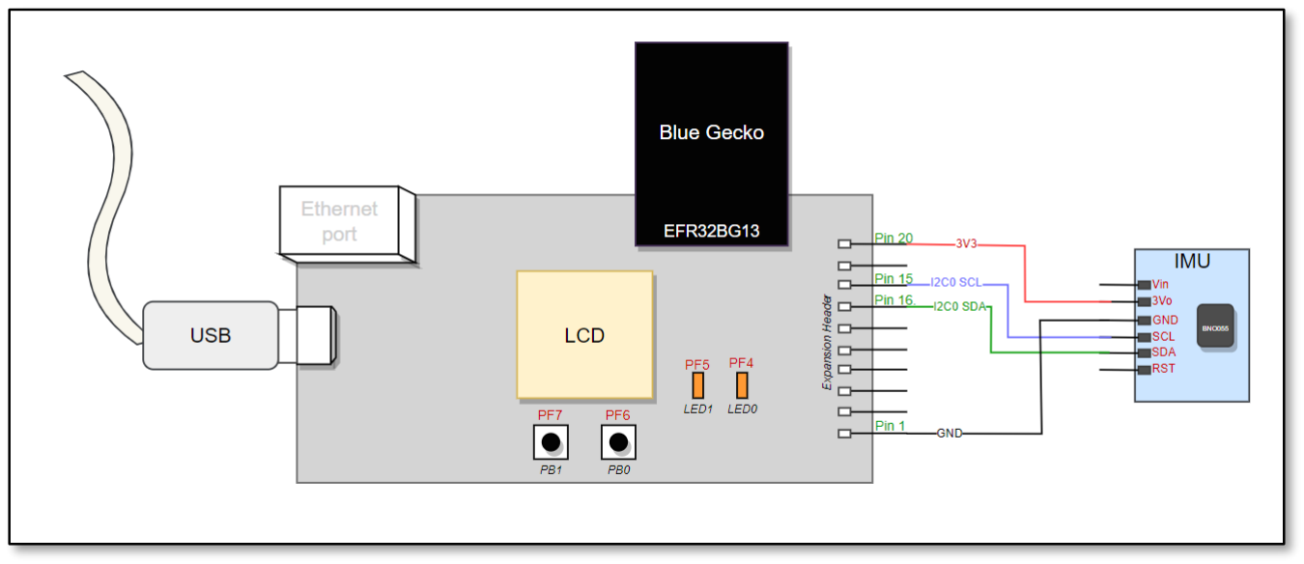
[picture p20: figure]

Figure 24 IMU Interface with Blue Gecko

- Program was written for I2C_FREQ_STANDARD_MAX which is 92KHz data transfer.
- Digilent’s Analog Discovery 2 logic analyzer was used to monitor the I2C transaction
- Hardware Interface and Logic analyzer trace is shown below.

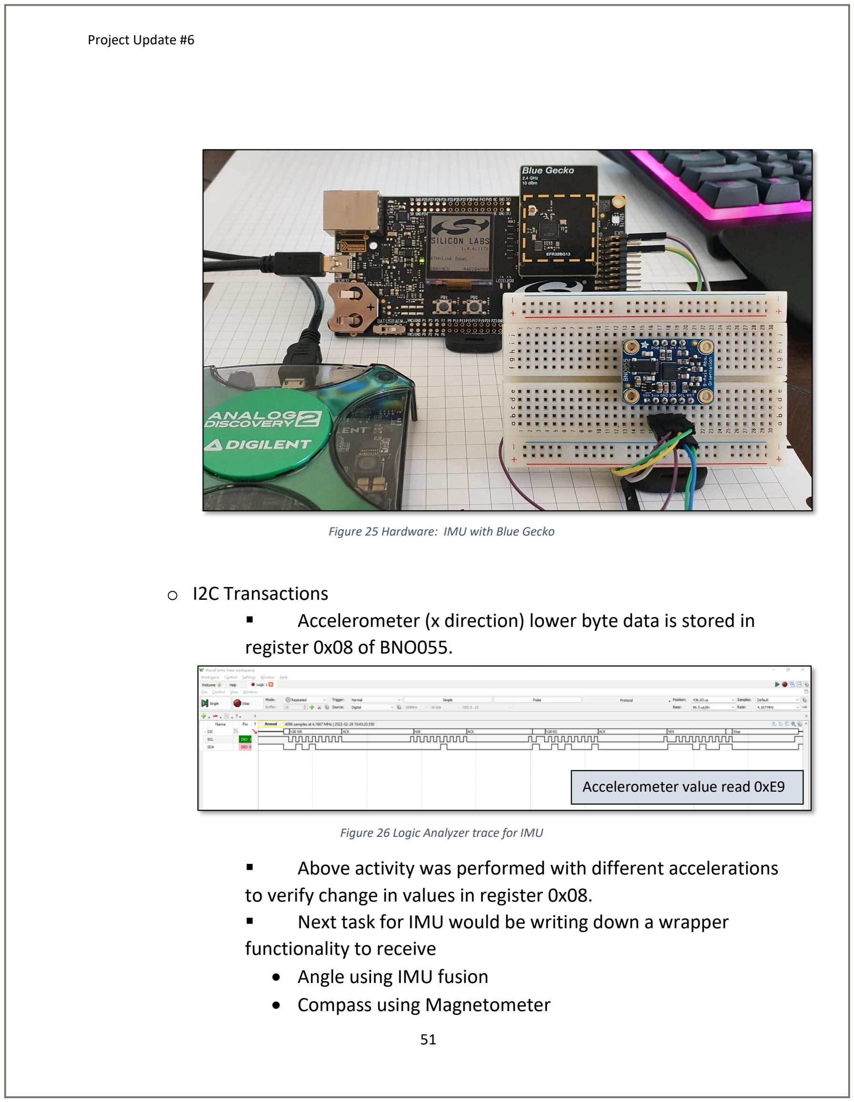
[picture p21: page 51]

Figure 25 Hardware: IMU with Blue Gecko

- I2C Transactions
- Accelerometer (x direction) lower byte data is stored in register 0x08 of BNO055.

Figure 26 Logic Analyzer trace for IMU
- Above activity was performed with different accelerations to verify change in values in register 0x08.
- Next task for IMU would be writing down a wrapper functionality to receive
- Angle using IMU fusion
- Compass using Magnetometer

Accelerometer value read 0xE9

### 6.1.2 Magnetic Encoder Bring-up

- AS5147P Interfacing with Blue Gecko
- Magnetic encoder uses Hall effect sensor AS5147 to detect change in magnetic field.
- It supports SPI, ABI, UVW and PWM interfaces. ABI interface would be appropriate for our application as we can keep microcontroller in lowest possible energy mode whenever there’s no activity.
- Connection diagram

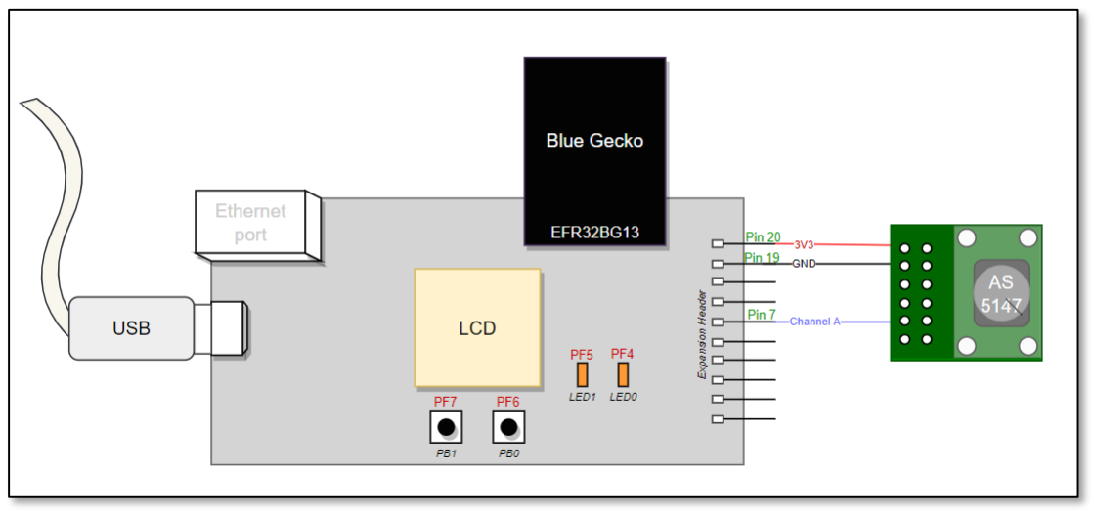
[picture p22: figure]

Figure 27 Magnetic Encoder Interface with Blue Gecko
- Program was written to receive interrupts on GPIO pin and keep the count of pulses for channel A of Magnetic encoder. This count was printed over serial terminal.
- Energy profiler was used to see variation in energy consumption as pulses were received.
- With current configuration 1024 pulses are received per revolution.
- It is configurable over SPI to receive 256 pulses per revolution
- Hardware Interface and Energy profiler shown below

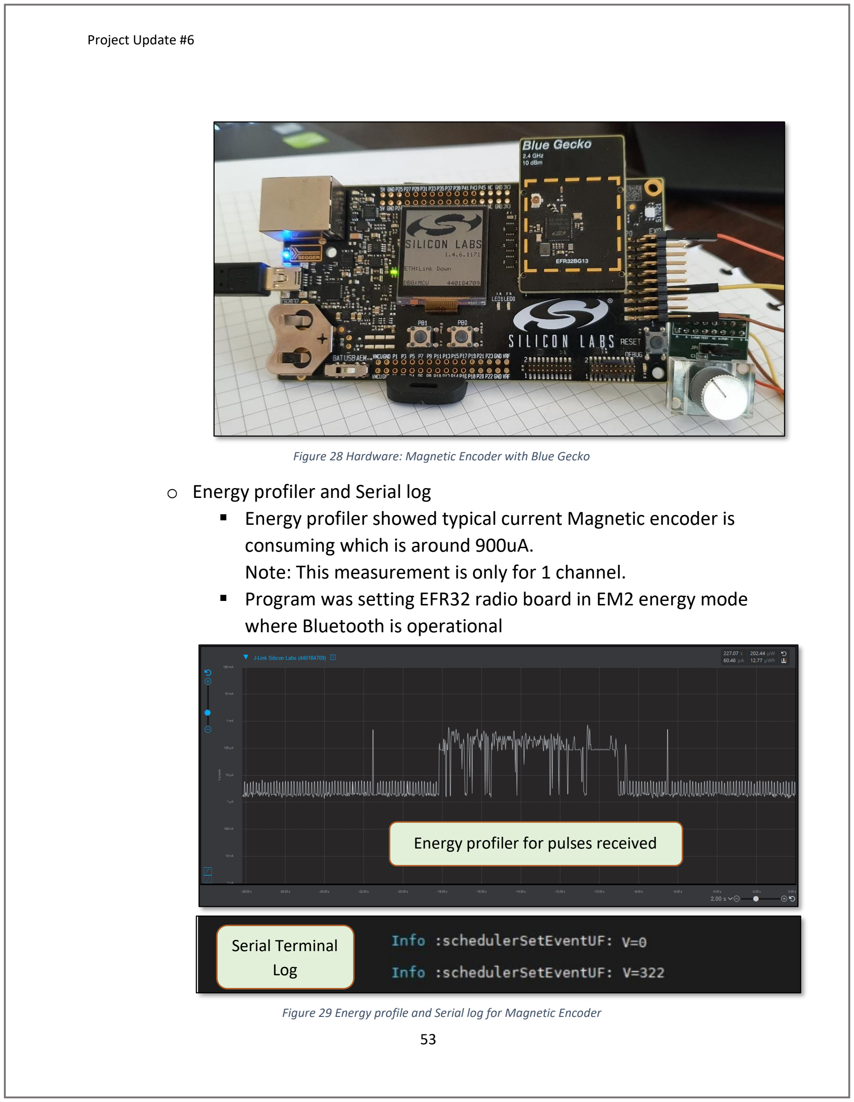
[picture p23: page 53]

Figure 28 Hardware: Magnetic Encoder with Blue Gecko
- Energy profiler and Serial log
- Energy profiler showed typical current Magnetic encoder is consuming which is around 900uA.
Note: This measurement is only for 1 channel.
- Program was setting EFR32 radio board in EM2 energy mode where Bluetooth is operational

Figure 29 Energy profile and Serial log for Magnetic Encoder

Energy profiler for pulses received

Serial Terminal
Log

- Challenges for magnetic encoder:
- It’s been observed that EFR32 for above operation is not able to handle 1024 pulses per revolution when wheel rotates faster. In fact, this much resolution is not required for this application.
- In order to resolve this, plan is to use low power frequency divider to reduce pulses. Required number of pulses per revolution to maintain stated measurement resolution can be calculated as follows

Assumption: Wheel diameter = 3cm

Circumference of wheel = π ∗ d = 9.42 cm

In order to maintain minimum resolution of 0.5cm, around 20 pulses are required per resolution.

Magnetic encoder can be operated in 256 ppr mode with configuration bits and this further can be divided by 8 using external frequency divider. This would result in 32 pulses per revolution.

### 6.1.3 Actual Bulk capacitor value required (considering the DC bias)

- As per our bulk capacitor calculations, Cubit board requires 100uF capacitor.
- In order to find out equivalent capacitance that would give 100uF, simsurfing tool from murata was used.
SimSurfing: Multilayer Ceramic Capacitors - Murata Manufacturing (https://ds.murata.co.jp/simsurfing/mlcc.html?lcid=en-us&jis=false&md5=5f242d800992593fcc24f15a095886ca)
- 220uF (GRM32ER60J227ME05L Murata Electronics | Capacitors | DigiKey) (https://www.digikey.com/en/products/detail/murata-electronics/GRM32ER60J227ME05L/7363052) was
selected based on following DC bias characteristic.
- 3.2v is our operational voltage for the entire circuit
- Effective bulk capacitor value @ 3.2v = 220 – 52.6% = 104.28uF

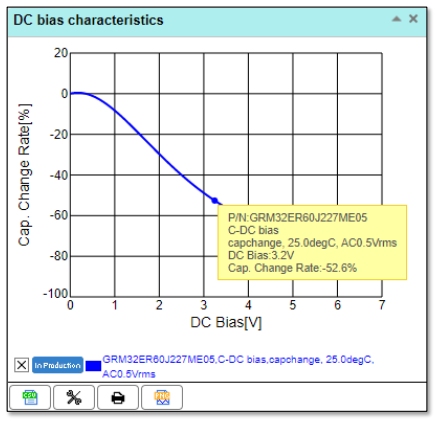
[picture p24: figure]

Figure 30 DC bias characteristics for bulk capacitor

### 6.1.4 IO Ports in design

- Buttons
- Menu selection switches
- Switches
- Operation Mode switch
Modes | Description
All OFF | External supply to PMIC would be disconnected
Partial ON | Only PMIC, EFR32 radio board and LCD would be Turned ON
All ON | All components and required sensors would be turned ON
- USB
- To be used for fast charging of battery where energy from energy source would not be available.
- Battery connector
- To be used for External Lipo battery

For above mentioned IO ports ESD protection would be required.

### 6.1.5 ESD protection

IO Ports | ESD part
HMI pushbutton switches (4) | SP1001-04JTG
USB | SP1003
Battery Connector | SP1003
- SP1003 part used for VBUS pin from USB connector and power pin from battery connector has clamping voltage of 12V which is closer to maximum allowable input voltage (5V) for PMIC BQ25570. Moreover, this part has low leakage current of 100nA (MAX) at 5V operation.
- SP1001 part used for ESD protection on push button switches satisfies the requirement of 4 I/O pins connection for 4 push-button switches.

# 6.2Activities planned for the upcoming week:

- Incorporate changes in board schematic suggested in the review
- Designing a layout for the final board
- Interface ultrasonic sensor with Blue Gecko development board.

## 7 Project Update 7 ECEN 5833: Low Power Embedded Design Techniques

# CUBIT

# Smart Measuring Instrument

Team Name: | Cubit
Team Members: | Saloni Shah
| Rajat Chaple
Date: | 03/12/2022

# 7.1 Activities accomplished in past week:

### 7.1.1 Testing of PWM output generation on Magnetic Encoder:

- The magnetic encoder gives output at the rate of minimum 256 pulses per rotation. Two different such output pulses must be interpreted by the controller to determine number of pulses generated and the direction of rotation.
- To avoid problem of having too many A-channel and B-channel pulses to process, alternative PWM is also available. This PWM output was tested on Arduino and Analog discovery 2. PWM signal gives absolute position of the sensor. In addition, Index signal give number of revolutions.
- Combination of PWM and Index would also give the total rotation.

- However, this would also require either the ADC (with filtered signal) or measuring time difference between rising and the falling edge. This PWM is at Frequency 558 Hz. This is also energy inefficient.
- Decision has been made to stick with the A-B channel output with frequency divider circuit in series.

### 7.1.2 Frequency divider for Magnetic Encoder output:

- The magnetic encoder gives output at the rate of minimum 256 pulses per rotation. Two different such output pulses must be interpreted by the controller to determine number of pulses generated and the direction of rotation.
- As per the challenges related to the encoder discussed in previous update, we monitored the pulses received on the controller at the rate of 12 rotations per second. As expected, while transitioning from lowest energy mode to a higher mode while receiving pulses, the controller missed some pulses due to time delay.
- For these reasons, we decided to include an additional frequency divider on the output of the encoder.
- CD74HC4520 is a high speed CMOS logic Dual Synchronous Counter. It is a dual binary up-counter which consists of two independent internally synchronous 4-state counters. The counter stages are D-flipflops to either increment on rising-edge or falling edge.
- The below image shows the timing diagram of 4-bit binary counter. In this component, we get the option of dividing the input by 1 (on Q0), by 2 (on Q1), by 4 (on Q2) and by 8 (on Q3). We will be using the Q3 output which divides the input by 8. This will reduce our magnetic encoder pulses to 32 pulses per rotation which will be computationally simpler for the controller.

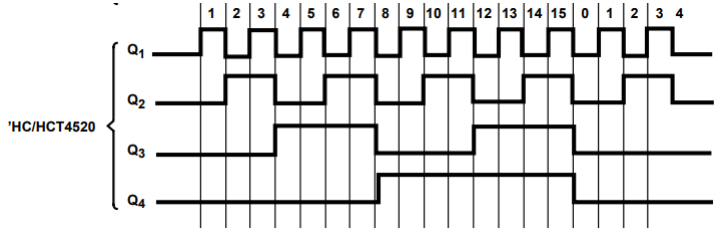
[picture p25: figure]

Figure 31 Frequency division timing diagram in CD74HC4520

### 7.1.3 Interfacing ultrasonic sensor with Blue Gecko development kit:

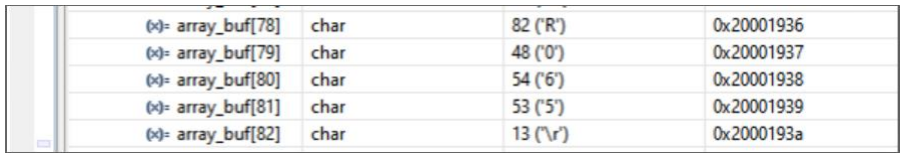
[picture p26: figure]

- Ultrasonic sensor communicates with Blue gecko over UART.
- USART2 was configured in interrupt mode to receive distance measurement. Sensor keeps sending data over Tx pin in the format R-distance-\r. Parser was written to process this data.
- Circular buffer was also implemented to manage variable rates of data in and data read. Above screen capture shows the data read and stored in the circular buffer.

### 7.1.4 Altium Board Layout:

- The above board fits in 100mm x 100mm.
- Perforation is to be used to separate out these multiple daughter boards:
- Main board
- HMI-Switch board
- Solar panel board

# 7.2Activities planned for the upcoming week:

- Incorporate changes in board layout suggested in the review
- Finalize board layout and place board fabrication order
- Complete the interfacing of ultrasonic sensor with Blue Gecko development board.
- Start working on configuring basic mobile application for the product.
- Development of initial software for the final board.

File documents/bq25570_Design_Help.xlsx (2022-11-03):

User Input | VBIAS | 1.21 | V
Fixed
 | Comparator threshold for VSTOR of charger. |  |  |  |  | Comparator threshold voltages indicating when |  |  |  |  | For the bq25570 only, comparator threshold |  |  |  |  | Maximum power point threshold, e.g. ~0.7-0.8 of
 | Typically the max storage element voltage, |  |  |  |  | VSTOR has risen above VBAT_OK_HYST or fallen |  |  |  |  | for VOUT of buck converter. |  |  |  |  | solar panel's open circuit voltage.
 | e.g. 4.2V for LiIon battery. |  |  |  |  | below VBAT_OK.
 | VBAT_UV < VBAT_OV < 5.5V |  |  |  |  | VBAT_OV > VBAT_OK_HYST > VBAT_UV |  |  |  |  | 1.3V < VOUT < VBAT_OV |  |  |  |  | MPPT
Desired |  |  |  |  |  | RSUM1 | 13 | MW |  |  |  |  |  |  |  | RSUM1 | 20 | MW
Desired | RSUM1 | 13 | MW |  |  | VBAT_OK | 2.8 | V | > VBAT_UV |  | RSUM1 | 13 | MW |  |  | VIN_DC(OC) | 1 | V | Open Circuit Volts
Desired | VBAT_OV | 4.2 | V |  |  | VBAT_OK_HYST | 3.1 | V | > VBAT_OK |  | VOUT | 1.3 | V |  |  | VREF_SAMP | 0.9 | V | MPP voltage
 |  |  |  |  |  |  |  | closest 1% resistor1 |  |  |  |  |  |  |  |  |  | closest 1% resistor1
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

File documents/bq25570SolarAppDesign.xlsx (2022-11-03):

User Input
Computed/Fixed
 |  |  | VSTOR nominal | 3.00 | V |  |  |  |  | VBAT_UV < VSTOR nominal <= VBAT_OV
System Loads | VOUT (V) | IOUT (mA) | Est Buck Effcy per datasheet | ISTOR = (VOUTxIOUT) / (VSTORnom x Effcy) (mA) | Mode Duration (how long?) (s) | Mode Period (how often?) (s) | Mode Hours / Day = 24 hours x duration/ period | mAHr / Day = ISTOR X Mode Hrs / Day | mWHr / Day = VSTOR x mAHr / Day
Active Mode 1 - bq25570 VOUT | 1.800 | 49.500 | 0.930 | 31.935
Active Mode 1 - bq25570 VSTOR |  |  |  | 8.000 |  |  |  |  |  | Direct loading on VSTOR
Totals for Active Mode 1 |  |  |  | 39.935 | 0.040 | 60.000 | 0.016 | 0.639 | 1.917
Active Mode 2 - bq25570 VOUT | 1.800 | 6.500 | 0.850 | 4.588 |  |  |  |  |  | If only one active mode, enter 0 for IOUT.
Active Mode 2 - bq25570 VSTOR |  |  |  | 5.500 |  |  |  |  |  | If only one active mode, enter 0 for ISTOR.
Totals for Active Mode 2 |  |  |  | 10.088 | 0.125 | 60.000 | 0.050 | 0.504 | 1.513
Sleep Mode - bq25570 VSTOR (1.8V rail off) |  |  |  | 0.100 |  |  | 23.934 | 2.393 | 7.180 | Idle mode hours / day = 24 minus active mode hours / day
bq25570 quiescent current + storage element leakage current |  |  |  | 0.001 |  |  | 24.000 | 0.024 | 0.072 | Storage element leaks all the time.
 | Total mAHr / day consumed |  |  |  |  |  |  | 3.561 | mAHr / day
 | Multiply by max consec dark days (e.g. not charging when overcast or raining) |  |  |  |  |  |  | 2.000 | days / week
 | Recommended minimum battery capacity |  |  |  |  |  |  | 7.122 | mAHr
 | -OR-
 | Mininum super capacitor voltage |  |  |  |  |  |  | 2.500 | V | VBAT_UV = 2.0V > Min super capacitor > VSTOR nominal
 | Maximum super capacitor voltage |  |  |  |  |  |  | 4.000 | V | VSTOR nominal < Max super capacitor voltage <= VBAT_OV
 | Recommended minimum super capacitance |  |  |  |  |  |  | 15.777 | F | Min Bat Capacity / 1000 x 3600s/hr x VSTORNOM = 1/2 x CSUPER x (Vmax2 - Vmin2)
 |  | Total mWHr / day consumed |  |  |  |  |  |  | 10.682 | mWHr / day
 |  | Multiply by operating days per week |  |  |  |  |  |  | 7.000 | days / week
 |  | Total mWHr /week required for system operation for the week |  |  |  |  |  |  | 74.776 | mWHr / week
 |  | Divide by charging days per week |  |  |  |  |  |  | 5.000 | days / week | Operating days minus max consecutive dark days
 |  | Total mWHr / day required to be collected by solar panel during charging days |  |  |  |  |  |  | 14.955 | mWHr / day | Total 7-day power must be collected during 5 charging days
 |  | Divide by charging hours / day |  |  |  |  |  |  | 8.000 | hours / day | i.e., includes excess energy for charging the battery
 |  | Instantaneous power required from the solar panel |  |  |  |  |  |  | 1.869 | mW
 |  |  | Divide by low estimate of bq25570 efficiency per datasheet |  |  |  |  |  | 0.800
 |  |  | Minimum input power required for system operation |  |  |  |  |  | 2.337 | mW
 |  |  |  | Divide by panel power per panel datasheet |  |  |  |  | 8.000 | mW/cm2 | Use power from lowest expected light level
 |  |  |  | Minimum solar panel area required |  |  |  |  | 0.292 | cm2

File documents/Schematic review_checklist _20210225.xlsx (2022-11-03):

 |  | Schematic Entry Review worksheet (Verstion 10-05-2019) | Schematic Entry Engineer Review comments /justifications | Partner 1 Engineer Schematic Review comments | Partner 2 Engineer (If team of 3) Schematic Review comments | SA Schematic Review 1 Comments | SA Schematic Review 2 Comments
 |  | Date: | 2022-02-27 | 2022-02-27
 |  | Engineeer/ Reviewer Name: | Saloni Shah | Rajat Chaple
 |  | Project name: Cubit
 |  | Circuits: Power Management, IO connection, Sensor interfacing, radio interface, HMI interface
1. Symbol Generation
 | a. Review all custom made .schLib files.
 |  | i. Verify that the schematic symbol is appropriate for the device function. | Schematic symbol designed using reference application design from datasheet | Schematic symbols verified
 |  | ii. If symbol is multipart, verify functional divisions make sense | Multipart symbols are EFR32 and BNO055. EFR32 has 3 parts - radio and antenna interface, IO port, power decoupling and supply. BNO055 has 2 parts - application pin connections and noconnect pins | Multipart symbols verified
 |  | iii. Make sure all component pins are accounted for on symbol(s). (Count them!) | Verified | Verified
 |  | iv. Verify the schematic pin #s match the data sheet. | Verified | Verified
 |  | v. If thermal pad is required, verify that a pin is specified for the pad and connected to ground. | Thermal pad is required in EFR32, BQ25570 only. Pads connected to ground. Verified | Thermal pads verified. Pads adjusted in footprint as well to get appropriate solder mask
 |  | vi. Review that the same IC package is selected on the merchant website and on the parameter entry in schematic symbol. | Verified | Verified
 | b. Verify that all the Parts have their part numbers updated. |  | Verified | Verified
 | c. Verify that all the segments of a multipart component have the same reference designator assigned. |  | Verified | Verified
2. Component Selection
 | a. Decoupling capacitor selected should be rated for 175 to 200% of the voltage on the rail. |  | 220uF and 100uF used in PMIC bulk capacitance and decoupling capacitance is rated at 6.3V, this was the highest available value. Rest of the capacitors are rated at higher voltages | Verified
 | b. Guideline, not rule: All resistor 0603 or justify a different size |  | All resistors used are 0603 | Verified
 |  | i. space constraints demand smaller, (don’t go smaller than 0402)
 |  | ii. or use case power requires larger
 | c. Guideline, not rule: All Caps 0805 or justify a different size |  | Most capacitors used are 0805 | Verified
 |  | i. space constraints demand smaller, (don’t go smaller than 0402)
 |  | ii. or capacitance requires larger package, | 220uF capacitor is larger (1210) as smaller size is not available | Capacitance calue verified using SimSurfer taking into account DC bias
 |  | iii. or smaller part required to achieve desired response frequency. | Smaller capacitance on antenna connection require 0402 part | Verified
3. Page Layout
 | a. Block diagram on first page. |  | Done by Rajat | Completed
 | b. Functional blocks grouped logically on pages |  | Verified | Verified
 | c. Pages not overcrowded |  | Verified | Verified
 | d. Schematics designed to print on 8.5 x 11” page (OK to use 'B' size sheet and shrink to print.) |  | Verified | Verified
 | e. Title blocks on all pages? Properly filled in? |  | Verified | Verified
4. Design
 | a. For every IC
 |  | i. Check voltages on each part. Verify that signals connecting devices are at the same voltages or are open collector (open Drain) signals. | All components can be configured between 3-3.6V. We are operating them at 3.2V for maximum battery usage | VOUT of 3.2V gives satisfies minimum requirement of all circuit components
 |  | ii. Check whether each signal pin is open drain, and if yes, is there a pull-up resistor. | N/A | N/A
 |  | iii. Verify the no device on a given bus will be powered down and pull the bus signals low when other devices are trying to communicate. | Verified | Verified
 | b. Go through the PMU datasheet to understand the settings.
 |  | i. Verify that the maximum voltages on any pins are within the device’s PMU specifications. | Verified | Verified
 |  | ii. Go through each PMU pin specification in order of the data sheet | Verified | Verified
 |  | iii. Check whether each pin requires a decoupling capacitor. | Verified (followed typical application for guidance) | Verified
 |  | iv. Show math for calculating all feedback components - best to show math on schematic. | Calculated using the excel sheet resource provided by TI | Verified the excel sheet calculation with equations given in PMIC datasheet
 |  | v. Show math for calculating all compensation components - best to show math on schematic. | Calculated using the excel sheet resource provided by TI | Verified the excel sheet calculation with equations gven in PMIC datasheet
 | c. What is the planned cut-off voltage of the battery? |  | 2 V
 |  | i. Confirm that the PMU is set to disable power to the digital circuit when the battery goes below the cut-off voltage | Internally managed by the PMIC | Verified
 | d. If design is different from reference schematic from vendor, why? |  | Same design except addition of Bulk capacitance on VSTOR and schottkey diode assembly on LBOOST input to handle input from USB connector | Design change verified by detailed study of PMIC datasheet
 |  | i. Justify changes
 | e. If super capacitor is chosen as the storage device, check for the leakage current. |  | N/A | N/A
 | f. Verify if the different modules can be isolated from each other to ease the testing process. |  | Load switches are connected before each sensor and LCD module for isolation. Jumper connection is added between PMIC and microcontroller for isolation | Load switches connected between power from microcontroller correctly. Can have additional jumpers before load switches for testing during development
 | g. Add a header on the energy harvester to check for current consumption. |  | Test point added on the solar panel output | Verified
 | h. If using UART and if the microprocessor is an EFM32LG, an external oscillator will be required as the RC Oscillator isn’t accurate enough to run at 9600 baud rate. |  | N/A | N/A
 | i. Every power pin on a part or header should have a decoupling capacitor. |  | Verified | Verified
 | j. Does design have an appropriate programming connector or method? |  | Debug connector added to EFR32 | Debug connector interfacing verified from AN958
 |  | i. Does design provide enough power for programming MCU or does it have an alternate programming power connection? | No alternate programming power connection required | Verified
 | k. Can battery or cap be initially powered in reasonable time?
 | l. Does schematic have extra GND test point pins to be spread around board? (6-8?) |  | Not required. All test points have adjacent ground connection | Verified
 | m. Test point pins on busses? |  | Verified | Verified
 | n. Test point pins on interrupts? |  | Verified | Verified
 | o. Extra test pins on spare IO for scope triggers for profiling? |  | Verified | Verified
 | p. Consider adding LED indicators, especially on the power rails and add it close the subsystem under test (easy to identify if the subsystem is powered on/off). |  | Added indicator LEDs on multiple parts of the board | Verified
5. Wiring
 | a. Verify the direction and use of the LEDs. |  | Verified | Verified
 | b. Verify that the GNDs have all the same name where ever required. |  | Verified | Verified
 | c. Verify that all appropriate power lines have the same name. |  | Verified | Verified
 | d. Verify any communication lines:
 |  | i. If one part will be active while another one is powered off on the line, is there a condition where an ESD diode could be pulling the line down? | No such connection made | Verified
 | e. Verify whether any UART RTS and CTS lines need to be shorted or left open. |  | Not required. | Verified
 | f. Verify that the micro controller UART TX pin connects to the RX pin of the slave device and that the TX pin of slave device connects to the RX pin of the microcontroller. |  | Verified. Ultrasonic sensor output TX pin is connected to EFR32 RX pin | Verified
 | g. Verify that the RESET pin is connected correctly as per the functionality (Active Low/Active High). |  | Verified. Using reference from EFR32 mainboard schematic | Verified
 | h. Reset button with proper pull-up / capacitor configuration |  | Verified | Verified
 | i. Can you justify the reset metodology for each digital component? |  | Reset not required for the other modules or sensors. | Verified
 | j. All signals should be correctly named. Do not use Altium default signal names. |  | Verified | Verified
 | k. Corectly name the signals of the communication lines in the schematics for ease in debugging. |  | Verified | Verified

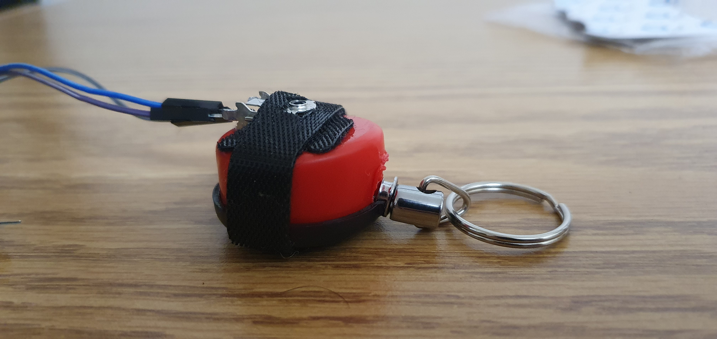
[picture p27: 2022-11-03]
images/Optical Rotary encoder 1.jpg

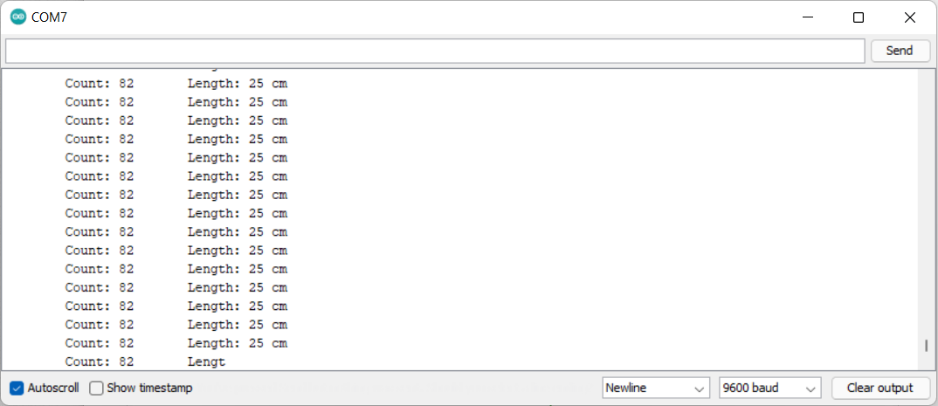
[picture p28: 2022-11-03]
images/Optical Rotary Encoder output.png

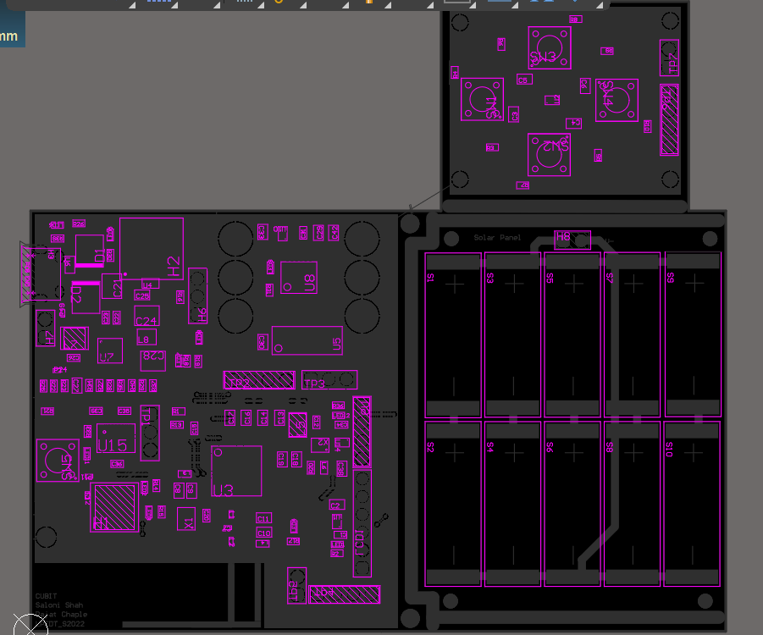
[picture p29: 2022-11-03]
hardware/lpedt_project_board_cubit/Screenshot 2022-04-06 115455.png

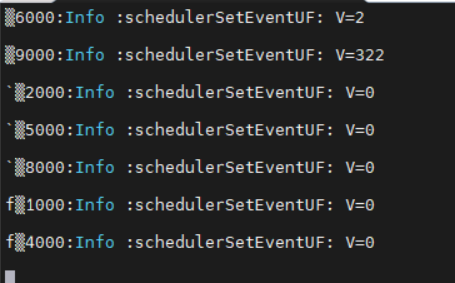
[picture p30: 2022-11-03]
images/Magnetic Encoder pulses on serial.png

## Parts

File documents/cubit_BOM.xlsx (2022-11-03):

Parts ordered from Digi-Key
Comment | Description | Designator | Footprint | LibRef | BOM Quantity | Order Quantity | Unit Price | Order Amount | Case/Package | Manufacturer | Manufacturer Part Number | Supplier 1
F_ANT |  | A1 | F_ANTENNA_FOOTPRINT | F_ANT | 1
0.1uF 16V | Cap Ceramic 0.1uF 16V X7R 10% SMD 0805 125°C Paper T/R | C1, C15, C20, C23, C31, C32, C35, C36, C37, C39 | CAP_0805_02X125 | C0805C104K4RACAUTO | 10 | 20 | 0.162 | 3.24 | 0805 | KEMET | C0805C104K4RACAUTO | Digi-Key
10uF 25V | Cap 0805 25 V 10 uF ±20% Tolerance X5R Monolithic Ceramic Chip Capacitor | C2, C13, C18, C25, C29, C30, C33, C34, C38, C40, C41, C42, C44, C46 | CAP_0805_02X125 | GRM21BR61E106KA73K | 14 | 50 | 0.094 | 4.7 | 0805 | Murata | GRM21BR61E106KA73K | Digi-Key
1nF 50V | 1nF ±10% 50V X7R 0805 | C3, C4, C5, C6 | CAP_0805_02X125 | CL21B102KBANFNC | 4 | 10 | 0.043 | 0.43 | 0805 | Samsung | CL21B102KBANFNC | Digi-Key
1.5pF 50V | Cap Ceramic 1.5pF 50V C0G 5% Pad SMD 0402 125C Automotive T/R | C7 | CAP_0402_1mm | GCM1555C1H1R5JA16D | 1 | 10 | 0.047 | 0.47 | 0402 | Murata | GCM1555C1H1R5JA16D | Digi-Key
100pF 50V | Cap 0.1nF ±10% 50V X7R 0805 | C8 | CAP_0805_02X125 | CC0805KRX7R9BB101 | 1 | 3 | 0.11 | 0.33 | 0805 | Yageo | CC0805KRX7R9BB101 | Digi-Key
10pF 50V | Cap Ceramic 10pF 50V X7R 10% SMD 0805 125°C Paper T/R | C9, C11 | CAP_0805_02X125 | C0805C100K5RACTU | 2 | 5 | 0.29 | 1.45 | 0805 | KEMET | C0805C100K5RACTU | Digi-Key
220nF 50V | Cap 220nF ±10% 50V X7R 0805 | C10 | CAP_0805_02X125 | CC0805KKX7R9BB224 | 1 | 3 | 0.18 | 0.54 | 0805 | Yageo | CC0805KKX7R9BB224 | Digi-Key
4.7uF 10V | Cap CL10 Series 4.7 uF 10 V ±10 % Tolerance X5R SMT Multilayer Ceramic Capacitor | C12, C22, C26 | CAP_0603_1MM | CL10A475KP8NNNC | 3 | 10 | 0.047 | 0.47 | 0603 | Samsung | CL10A475KP8NNNC | Digi-Key
1uF 25V | Cap 1 µF ±10% 25V Ceramic Capacitor X5R 0805 (2012 Metric) | C14, C16, C17 | CAP_0805_02X125 | GRM216R61E105KA12D | 3 | 10 | 0.266 | 2.66 | 0805 | Murata | GRM216R61E105KA12D | Digi-Key
10nF 50V | Cap 10nF ±10% 50V X7R 0805 | C19, C27 | CAP_0805_02X125 | CL21B103KBCNNNC | 2 | 10 | 0.05 | 0.5 | 0805 | Samsung | CL21B103KBCNNNC | Digi-Key
220uF 6.3V | Cap 220uF 6.3volts X5R 20% | C21 | Chip_1210_3.2x2.5 | GRM32ER60J227ME05L | 1 | 2 | 1.62 | 3.24 |  | Murata | GRM32ER60J227ME05L | Digi-Key
100uF 10V | Cap 100uF ±20% 10V X5R 1210 | C24, C28 | Chip_1210_3.2x2.5 | CL32A107MPVNNNE | 2 | 4 | 1.14 | 4.56 | 1210 | Samsung | CL32A107MPVNNNE | Digi-Key
Schottky Diode | LSM115J Series 15 V 1 A Surface Mount Schottky Rectifier - DO-214BA | D1, D2 | SCHOTTKY4336X33N | LSM115JE3/TR13 | 2 | 4 | 0.56 | 2.24 |  | Microchip | LSM115JE3/TR13 | Digi-Key
Debug Port Header | CONN HEADER SMD 10POS 1.27MM. Connector Header Surface Mount 10 position 0.050" | H1 | Amphenol_20021121_0 | 20021121-00010C1LF | 1 | 2 | 0.93 | 1.86 |  | Amphenol ICC / FCI | 20021121-00010C1LF | Digi-Key
Battery Connector | 2.00mm Pitch Mi ll System Wire-to-Board Header, Surface Mount, Single Row, Vertical, 2 Circuits | H2 | BAT_CONN | ‎PRT-09914 | 1 | 2 | 0.95 | 1.9 |  | SparkFun | ‎PRT-09914 | Digi-Key
USB MICRO B RECPT | USB - micro B USB 2.0 Receptacle Connector 5 Position Surface Mount, Right Angle; Through Hole | H3 | MICROUSB_AMPHENOL_10118194-0001LF | 10118194-0001LF | 1 | 2 | 0.48 | 0.96 |  | Amphenol FCI | 10118194-0001LF | Digi-Key
External Power Connector |  | H4, H7, H8 | 2_PIN_100mil | ext_pwr_conn | 3 |  |  | 0
PREC003SAAN-RC | Connector Header Through Hole 3 position 0.100" (2.54mm) | H5, H6 | 3_PIN_100mil | SW_3Pin_100mil_Switch | 2 |  |  | 0
1.9nH 1A | Inductor Chip 1.9nH 0.3nH Tolerance 2-Pin 0402 Paper T/R | L1, L2 | CAP_0402_1mm | LQG15WZ1N9S02D | 2 | 4 | 0.14 | 0.56 |  | Murata | LQG15WZ1N9S02D | Digi-Key
600ohm 500mA | Ferrite Beads 0603 600Ω ±25% DCR=0.38Ω 500mA | L3, L4 | IND_FERRITE_0603_1.6x0.4 | BLM18AG601SN1D | 2 | 5 | 0.1 | 0.5 | 0603 | Murata | BLM18AG601SN1D | Digi-Key
4.7uH 1.2A | Inductor FIXED IND 4.7UH 1.2A 186 MOHM | L5 | 2_IND_32X25 | LQH32PH4R7NNCL | 1 | 2 | 0.4 | 0.8 | Nonstandard | Murata | LQH32PH4R7NNCL | Digi-Key
1k 200mA | Ferrite Beads WE-CBF 0603 SMD Bead 100MHz 1000Ohm 200mA | L6 | CAP_0603_1MM | 74279266 | 1 | 2 | 0.18 | 0.36 | SMD/SMT | Wurth Electronics | 74279266 | Digi-Key
22uH | Inductor Power Shielded Wirewound 22uH 20% 1MHz Ferrite 0.87A 0.496Ohm DCR 1212 T/R | L7 | 2_IND_3x3 | VLS3015CX-220M-1 | 1 | 2 | 0.4 | 0.8 |  | TDK | VLS3015CX-220M-1 | Digi-Key
10uH 1A | Inductor Power Shielded Multi-Layer 10uH 20% 1MHz Metal 0.85A 0.46Ohm DCR 1008 T/R | L8 | 2_chip_2.5x2 | 1239AS-H-100M=P2 | 1 | 2 | 0.39 | 0.78 | 1008 | Murata | 1239AS-H-100M=P2 | Digi-Key
SHARP MEMORY Adafruit | Conn AV RCA (Phono) Plug 2 Cont Sz 0.125" Cbl Mnt Clamp Copper Alloy | LCD1 | LCD_SHARP_MEMORY_9_PIN | 3502 | 1 |  |  | 0 |  | Adafruit Industries | 3502 | Digi-Key
Green LED | Led Green Clear 0603 SMD | LED1, LED4, LED9, LED10, LED11, LED12 | LED_0603_RED_WL-SMCW | QBLP601-AG1 | 6 | 12 | 0.19 | 2.28 |  | QT-Brightek | QBLP601-AG1 | Digi-Key
150060YS75000 | Led, Yellow, 590 Nm, 2 V, 30 Ma, 120 Mcd Rohs Compliant: Yes | LED2, LED3 | LED_0603_RED_WL-SMCW | 150060YS75000 | 2 | 5 | 0.15 | 0.75 | 0603 | Wurth Electronics | 150060YS75000 | Digi-Key
150060RS75000 | LED Low-Power Uni-Color Red 630nm 2V 2-Pin Chip 0603(1608Metric) T/R | LED5, LED6, LED7, LED8 | LED_0603_RED_WL-SMCW | 150060RS75000 | 4 | 10 | 0.15 | 1.5 | 0603 | Wurth Electronics | 150060RS75000 | Digi-Key
4.7k 1% | Res Thick Film 0603 4.7K Ohm 1% 1/10W ±100ppm/°C Molded SMD Paper T/R | R1, R13 | CAP_0603_1MM | AF0603FR-074K7L | 2 | 10 | 0.061 | 0.61 | 0603 | Yageo | AF0603FR-074K7L | Digi-Key
1k 1% | Res 1K Ohm 1% 0.1W(1/10W) ±100ppm/C Pad SMD Automotive T/R | R2, R14, R15, R17, R18, R19, R30, R31, R32, R33, R36 | 2_Chip_0603_RMCF | RMCF0603FT1K00 | 11 | 25 | 0.017 | 0.425 | 0603 | Stackpole Electronics | RMCF0603FT1K00 | Digi-Key
1M 1% | Res 1M Ohm 1% 1/10W ±100ppm/°C Molded SMD Paper T/R | R3, R5, R6, R9 | 2_Chip_0603_RMCF | RMCF0603FT1M00 | 4 | 10 | 0.017 | 0.17 | 0603 | Stackpole Electronics | RMCF0603FT1M00 | Digi-Key
100 1% | Res 100 Ohm 1% 1/10W ±100ppm/°C Molded SMD SMD Paper T/R | R4, R7, R8, R10, R21 | 2_Chip_0603_RMCF | RMCF0603FT100R | 5 | 15 | 0.017 | 0.255 | 0603 | Stackpole Electronics | RMCF0603FT100R | Digi-Key
0 5% | Res 0 Ohms ±5% 0.063 W 0402 Thick Film Surface Mount Chip Resistor | R11, R12, R24, R49 | CAP_0402_1mm | RC1005J000CS | 4 | 10 | 0.042 | 0.42 | 0402 | Samsung | RC1005J000CS | Digi-Key
1 1% | Res 1 Ohm 1% 1/10W ±200ppm/°C Molded SMD SMD Paper T/R | R16, R20 | CAP_0603_1MM | RC0603FR-101RL | 2 | 10 | 0.048 | 0.48 | 0603 | Yageo | RC0603FR-101RL | Digi-Key
10M 1% | Res 10M Ohm 1% 1/10W ±200ppm/°C Molded SMD SMD Paper T/R | R22 | 2_Chip_0603_RMCF | RMCF0603FT10M0 | 1 | 10 | 0.025 | 0.25 | 0603 | Stackpole Electronics | RMCF0603FT10M0 | Digi-Key
2M 1% | RES 2M OHM 1% 1/10W 0603 | R23 | 2_Chip_0603_RMCF | RMCF0603FT2M00 | 1 | 10 | 0.025 | 0.25 | 0603 | Stackpole Electronics | RMCF0603FT2M00 | Digi-Key
7.87M 1% | Res 7.87M Ohm 1% 1/10W ±200ppm/°C Molded SMD SMD Paper T/R | R25 | 2_Chip_0603_RMCF | RMCF0603FT7M87 | 1 | 10 | 0.025 | 0.25 | 0603 | Stackpole Electronics | RMCF0603FT7M87 | Digi-Key
20 1% | Res High Voltage 0603 20 Ohm 1/10W 1% SMD | R26 | 2_Chip_0603_RMCF | KTR03EZPF20R0 | 1 | 3 | 0.17 | 0.51 | 0603 | Rohm | KTR03EZPF20R0 | Digi-Key
7.32M 1% | Res 7.32M Ohm 1% 1/10W ±200ppm/°C Molded SMD SMD Paper T/R | R27, R35 | 2_Chip_0603_RMCF | RMCF0603FT7M32 | 2 | 10 | 0.025 | 0.25 | 0603 | Stackpole Electronics | RMCF0603FT7M32 | Digi-Key
1.43M 1% | Res 1.43M Ohm 1% 1/10W ±200ppm/°C Molded SMD SMD Paper T/R | R28 | 2_Chip_0603_RMCF | RMCF0603FT1M43 | 1 | 10 | 0.025 | 0.25 | 0603 | Stackpole Electronics | RMCF0603FT1M43 | Digi-Key
8.06M 1% | Res 8.06M Ohm 1% 1/10W ±200ppm/°C Molded SMD SMD Paper T/R | R29 | 2_Chip_0603_RMCF | RMCF0603FT8M06 | 1 | 10 | 0.025 | 0.25 | 0603 | Stackpole Electronics | RMCF0603FT8M06 | Digi-Key
5.62M 1% | Res 5.62M Ohm 1% 1/10W ±200ppm/°C Molded SMD SMD Paper T/R | R34 | 2_Chip_0603_RMCF | RMCF0603FT5M62 | 1 | 10 | 0.025 | 0.25 | 0603 | Stackpole Electronics | RMCF0603FT5M62 | Digi-Key
4.87M 1% | Res 4.87M Ohm 1% 1/10W ±200ppm/°C Molded SMD SMD Paper T/R | R37 | 2_Chip_0603_RMCF | RMCF0603FT4M87 | 1 | 10 | 0.025 | 0.25 | 0603 | Stackpole Electronics | RMCF0603FT4M87 | Digi-Key
3k 1% | Res 3000Ω ± 1.00% 0.1W ± 100ppm/℃ 0603 | R39 | CAP_0603_1MM | RC0603FR-073KL | 1 | 10 | 0.024 | 0.24 | 0603 | Yageo | RC0603FR-073KL | Digi-Key
4.42M 1% | Res 4.42M Ohm 1% 1/10W ±200ppm/°C Molded SMD SMD Paper T/R | R40 | 2_Chip_0603_RMCF | RMCF0603FT4M42 | 1 | 10 | 0.025 | 0.25 | 0603 | Stackpole Electronics | RMCF0603FT4M42 | Digi-Key
Solar Cell | MONOCRYS SOLAR CELL 30.7MW 690MV | S1, S2, S3, S4, S5, S6, S7, S8, S9, S10 | KXOB25-14X1F | KXOB25-14X1F | 10 | 10 | 2.296 | 22.96
TL3301DF160QG | Tactile Switch SPST-NO Top Actuated Surface Mount | SW1, SW2, SW3, SW4, SW5 | SW_TL3301DF160QG | TL3301DF160QG | 5 | 10 | 0.447 | 4.47
10x Probe TP | Test Point 300 mil centers | TP1, TP2, TP3, TP4, TP5, TP6, TP7, TP8, TP9, TP10, TP11, TP12, TP13, TP14, TP15, TP16, TP17, TP18, TP19, TP20, TP21, TP22, TP23, TP24, TP25 | TP10x_Probe | TP_10x_Probe | 25 |  |  | 0
Load SW | 5.5-V, 0.1-A, 500-mΩ, load switch with current limit and active low enable 5-SC70 -40 to 85 | U1, U10, U11, U14 | SOT65P210X110-5N | TPS22942DCKR | 3 | 6 | 1.24 | 7.44 | SC | Texas Instruments | TPS22942DCKR | Digi-Key
ESD-SP1001 | TVS DIODE 5.5VWM 13VC SC70-5 | U2 | SOT65P210X110-5N | SP1001-04JTG | 1 | 2 | 0.61 | 1.22 | SC | Littelfuse | SP1001-04JTG | Digi-Key
EFR32BG13 | Blue Gecko QFN48 2.4 G 19 dB BLE/Proprietary 512 kB 64 kB(RAM) 31GPIO | U3 | 48-QFN_7x7 | EFR32BG13P732F512GM48-D | 1 |  |  | 0 |  | Silicon Labs | EFR32BG13P732F512GM48-D | Digi-Key
ESD-SP1003 | TVS DIODE 5VWM 12VC SOD723 | U4, U5, U6 | Littelfuse_Inc_SP1003_MFG | SP1003-01DTG | 3 | 6 | 0.57 | 3.42 |  | Littelfuse | SP1003-01DTG | Digi-Key
BQ25570 | Switching Battery Charger Li-Ion/Li-Pol/Supercapacitor 110mA 2.2V to 5.5V 20-Pin VQFN EP T/R | U7 | 21_QFN_35x35 | BQ25570RGRT | 1 | 2 | 8.95 | 17.9 | VQFN | Texas Instruments | BQ25570RGRT | Digi-Key
AS5147P | Rotary Position Sensor 5.5V/3.6V Digital Output Automotive 14-Pin TSSOP T/R | U8, U9 | 14-TSOP_5x4_4 | AS5147P-HTSM | 1 | 2 | 9.56 | 19.12 |  | ams | AS5147P-HTSM | Digi-Key
Ultrasonic Sensor |  | U13 | 7_PIN_100MIL | Ultrasonic Sensor | 1 |  |  | 0
BNO005 |  | U15 | LGA28R50P4X10_380X520X100 | BNO055 | 1 |  |  | 0
38.4MHz | Crystal 38.4000MHZ 10PF SMD | X1 | OSC_38.4MHz | RH100-38.400-10-F-1010-TR | 1 | 2 | 0.39 | 0.78 |  | Raltron Electronics | RH100-38.400-10-F-1010-TR | Digi-Key
32.768 kHz | Oscillator XO 0.032768MHz ±25ppm 15pF CMOS 60% 1.8V 4-Pin SMD T/R | X2 | OSC_ASDDV-48.000MHZ-LC-T | ASDK2-32.768KHZ-LR-T3 | 1 | 2 | 0.97 | 1.94 | SMD/SMT | Abracon | ASDK2-32.768KHZ-LR-T3 | Digi-Key
Male pin headers |  |  |  | 77311-418-00LF‎ |  | 30 | 0.054 | 1.62 |  | Amphenol CS (FCI)
LiPo Battery |  |  |  | LP802036JU+PCM+2 WIRES 50MM |  | 1 | 9.51 | 9.51 |  | Jauch Quartz
 |  |  |  |  |  |  | Total Amount | 133.62
Parts Acquired from Professor Randy
EFR32BG13 |  |  |  |  |  | 2 | 7 | 14
BNO055 |  |  |  |  |  | 2 | 9.3 | 18.6
 |  |  |  |  |  |  | Total BOM amount | 166.22

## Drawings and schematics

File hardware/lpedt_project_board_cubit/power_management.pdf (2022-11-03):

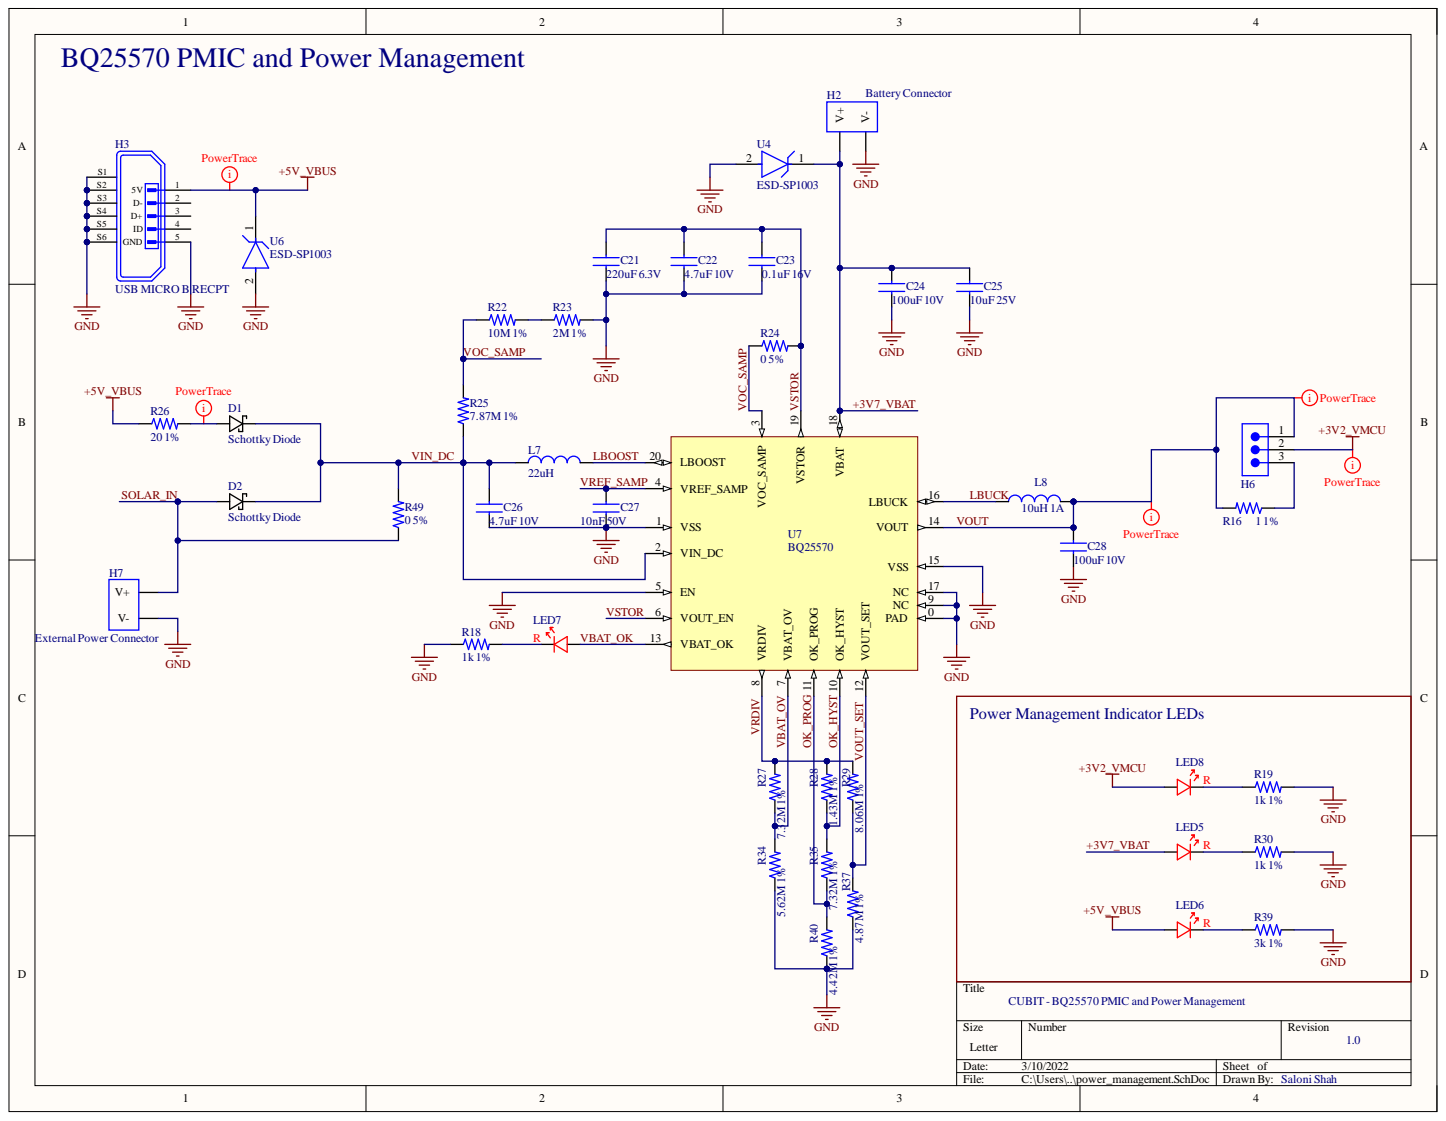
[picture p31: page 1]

BQ25570 PMIC and Power Management

Power Management Indicator LEDs

CUBIT - BQ25570 PMIC and Power Management

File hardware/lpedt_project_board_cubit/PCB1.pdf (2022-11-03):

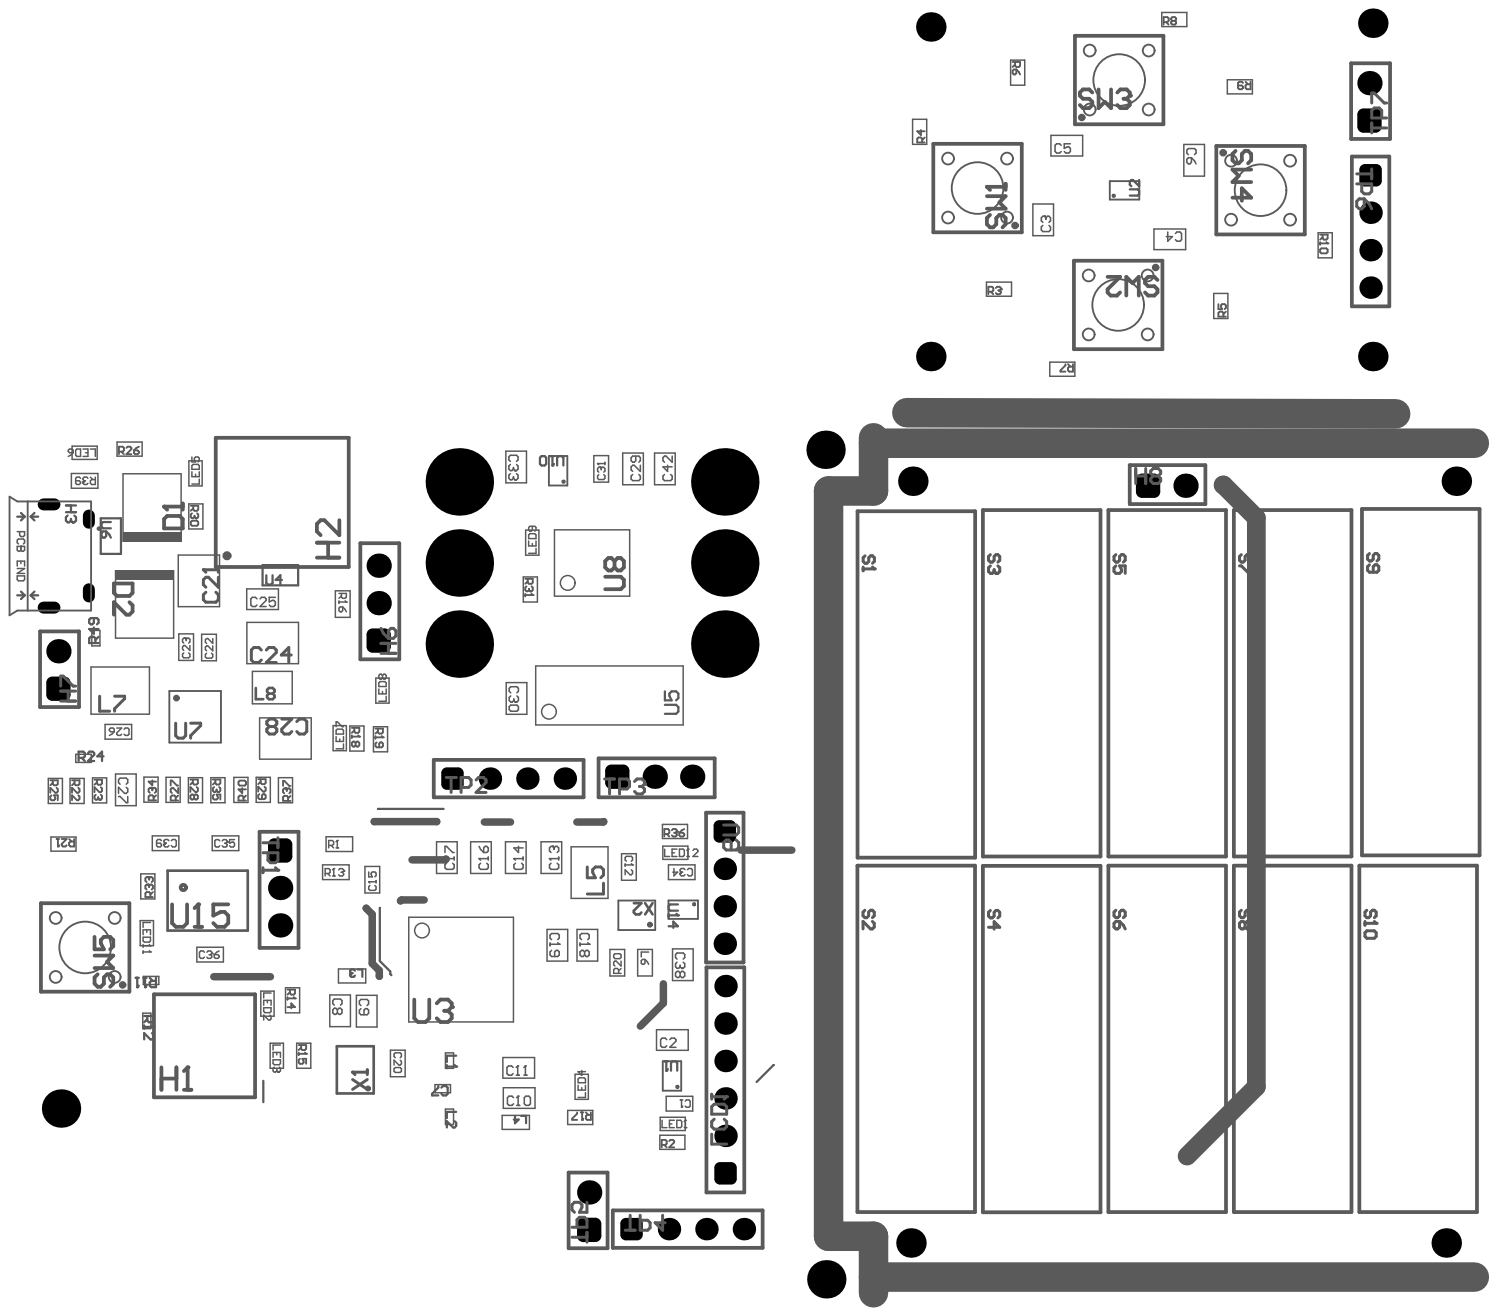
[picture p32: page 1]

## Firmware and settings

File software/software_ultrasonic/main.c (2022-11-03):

/***************************************************************************//**
 * @file
 * @brief main() function.
 *******************************************************************************
 * # License
 * <b>Copyright 2020 Silicon Laboratories Inc. www.silabs.com</b>
 *******************************************************************************
 *
 * SPDX-License-Identifier: Zlib
 *
 * The licensor of this software is Silicon Laboratories Inc.
 *
 * This software is provided 'as-is', without any express or implied
 * warranty. In no event will the authors be held liable for any damages
 * arising from the use of this software.
 *
 * Permission is granted to anyone to use this software for any purpose,
 * including commercial applications, and to alter it and redistribute it
 * freely, subject to the following restrictions:
 *
 * 1. The origin of this software must not be misrepresented; you must not
 *    claim that you wrote the original software. If you use this software
 *    in a product, an acknowledgment in the product documentation would be
 *    appreciated but is not required.
 * 2. Altered source versions must be plainly marked as such, and must not be
 *    misrepresented as being the original software.
 * 3. This notice may not be removed or altered from any source distribution.
 *
 * Date:        08-07-2021
 * Author:      Dave Sluiter
 * Description: This code was created by the Silicon Labs application wizard
 *              and started as "Bluetooth - SoC Empty".
 *              It is to be used only for ECEN 5823 "IoT Embedded Firmware".
 *              The MSLA referenced above is in effect.
 *              
 *              This code was written with:
 *                  Gecko SDK 3.2.1
 *                  GNU ARM 10.2.1
 *
 ******************************************************************************/

#include "main.h"

// Include logging for this file
#define INCLUDE_LOG_DEBUG 1
#include "src/log.h"
#include "src/imu.h"




int main(void)
{

  // Initialize Silicon Labs device, system, service(s) and protocol stack(s).
  // Note that if the kernel is present, processing task(s) will be created by
  // this call.
  sl_system_init();

  // Initialize the application. For example, create periodic timer(s) or
  // task(s) if the kernel is present.
  // Students: Place all of your 1 time initialization code in this function.
  //           See app.c
  app_init();

//  init_imu();

#if defined(SL_CATALOG_KERNEL_PRESENT)

  // Start the kernel. Task(s) created in app_init() will start running.
  sl_system_kernel_start();

#else // SL_CATALOG_KERNEL_PRESENT

  // The so-called super-loop, sometimes called: "the main while(1) loop"
  while (1) {

      // Do not remove this call: Silicon Labs components process action routine
      // must be called from the super loop.
      // Students: This call will eventually call the function sl_bt_on_event()
      // defined in app.c which we will discuss in lecture and learn more about
      // in later programming assignments. Do not remove this call.
      sl_system_process_action();

      // Application process. See app.c
      app_process_action();

#if defined(SL_CATALOG_POWER_MANAGER_PRESENT)
      // Let the CPU go to sleep if the system allows it.
      sl_power_manager_sleep();
#endif

  } // while

#endif // SL_CATALOG_KERNEL_PRESENT

} // main()



//
///***************************************************************************//**
// * @file main_tg11.c
// * @brief This project reads input on the UART RX port and echoes it back to the
// * TX port one line at a time. It does not use the VCOM or stdio. See readme.txt
// * for details.
// *******************************************************************************
// * # License
// * <b>Copyright 2020 Silicon Laboratories Inc. www.silabs.com</b>
// *******************************************************************************
// *
// * SPDX-License-Identifier: Zlib
// *
// * The licensor of this software is Silicon Laboratories Inc.
// *
// * This software is provided 'as-is', without any express or implied
// * warranty. In no event will the authors be held liable for any damages
// * arising from the use of this software.
// *
// * Permission is granted to anyone to use this software for any purpose,
// * including commercial applications, and to alter it and redistribute it
// * freely, subject to the following restrictions:
// *
// * 1. The origin of this software must not be misrepresented; you must not
// *    claim that you wrote the original software. If you use this software
// *    in a product, an acknowledgment in the product documentation would be
// *    appreciated but is not required.
// * 2. Altered source versions must be plainly marked as such, and must not be
// *    misrepresented as being the original software.
// * 3. This notice may not be removed or altered from any source distribution.
// *
// *******************************************************************************
// * # Evaluation Quality
// * This code has been minimally tested to ensure that it builds and is suitable
// * as a demonstration for evaluation purposes only. This code will be maintained
// * at the sole discretion of Silicon Labs.
// ******************************************************************************/
//
//#include "em_device.h"
//#include "em_chip.h"
//#include "em_emu.h"
//#include "em_cmu.h"
//#include "em_gpio.h"
//#include "em_usart.h"
//
//#include "bsp.h"
//
//// Size of the buffer for received data
//#define BUFLEN  80
//
//// Receive data buffer
//uint8_t buffer[BUFLEN];
//
//// Current position ins buffer
//uint32_t inpos = 0;
//uint32_t outpos = 0;
//
//// True while receiving data (waiting for CR or BUFLEN characters)
//bool receive = true;
//
///**************************************************************************//**
// * @brief
// *    GPIO initialization
// *****************************************************************************/
//void initGpio(void)
//{
//  CMU_ClockEnable(cmuClock_GPIO, true);
//
//  // Configure VCOM transmit pin to board controller as an output
//  GPIO_PinModeSet(BSP_BCC_TXPORT, BSP_BCC_TXPIN, gpioModePushPull, 1);
//
//  // Configure VCOM reeive pin from board controller as an input
//  GPIO_PinModeSet(BSP_BCC_RXPORT, BSP_BCC_RXPIN, gpioModeInput, 0);
//
//  // Enable VCOM connection to board controller
//  GPIO_PinModeSet(BSP_BCC_ENABLE_PORT, BSP_BCC_ENABLE_PIN, gpioModePushPull, 1);
//}
//
///**************************************************************************//**
// * @brief
// *    USART1 initialization (VCOM on xG1/xG12/xG13 boards)
// *****************************************************************************/
//void initUsart1(void)
//{
//  CMU_ClockEnable(cmuClock_USART1, true);
//
//  // Default asynchronous initializer (115.2 Kbps, 8N1, no flow control)
//  USART_InitAsync_TypeDef init = USART_INITASYNC_DEFAULT;
//
//  // Configure and enable USART1
//  USART_InitAsync(USART1, &init);
//
//  // Enable NVIC USART sources
//  NVIC_ClearPendingIRQ(USART1_IRQn);
//  NVIC_EnableIRQ(USART1_IRQn);
//
//  // Enable RX and TX for USART1 VCOM connection
//  USART1->ROUTELOC0 = BSP_BCC_RX_LOCATION | BSP_BCC_TX_LOCATION;
//  USART1->ROUTEPEN |= USART_ROUTEPEN_RXPEN | USART_ROUTEPEN_TXPEN;
//}
//
///**************************************************************************//**
// * @brief
// *    The USART1 receive/transmit interrupt processes characters.
// *****************************************************************************/
//void USART1_IRQHandler(void)
//{
//  // In the receive state
//  if (receive)
//  {
//    // Get the character just received
//    buffer[inpos] = USART1->RXDATA;
//
//    // Exit loop on new line or buffer full
//    if ((buffer[inpos] != '\r') && (inpos < BUFLEN))
//      inpos++;
//    else
//      receive = false;   // Stop receiving on CR
//  }
//  // In the transmit state
//  else
//  {
//    // Send a previously received character
//    if (outpos < inpos)
//      USART1->TXDATA = buffer[outpos++];
//    else
//    /*
//     * Need to disable the transmit buffer level interrupt in this IRQ
//     * handler when done or it will immediately trigger again upon exit
//     * even though there is no data left to send.
//     */
//    {
//      receive = true;   // Go back into receive when all is sent
//      USART_IntDisable(USART1, USART_IEN_TXBL);
//    }
//  }
//}
//
///**************************************************************************//**
// * @brief
// *    Main function
// *****************************************************************************/
//int main(void)
//{
//  uint32_t i;
//
//  // Chip errata
//  CHIP_Init();
//
//  // Initialize GPIO and USART0
//  initGpio();
//  initUsart1();
//
//  while (1)
//  {
//    // Zero out buffer
//    for (i = 0; i < BUFLEN; i++)
//      buffer[i] = 0;
//
//    // Enable receive data valid interrupt
//    USART_IntEnable(USART1, USART_IEN_RXDATAV);
//
//    // Wait in EM1 while receiving to reduce current draw
//    while (receive)
//      EMU_EnterEM1();
//
//    // Disable receive data valid interrupt
//    USART_IntDisable(USART1, USART_IEN_RXDATAV);
//
//    // Enable transmit buffer level interrupt
//    USART_IntEnable(USART1, USART_IEN_TXBL);
//
//    // Wait in EM1 while transmitting to reduce current draw
//    while (!receive)
//      EMU_EnterEM1();
//
//    // Reset buffer indices
//    inpos = outpos = 0;
//  }
//}

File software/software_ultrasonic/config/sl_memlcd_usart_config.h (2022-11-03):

#ifndef SL_MEMLCD_CONFIG_H
#define SL_MEMLCD_CONFIG_H

#define EXTERNAL_LCD

#ifndef EXTERNAL_LCD
// <<< sl:start pin_tool >>>
// <usart signal=TX,CLK> SL_MEMLCD_SPI
// $[USART_SL_MEMLCD_SPI]
#define SL_MEMLCD_SPI_PERIPHERAL                 USART1
#define SL_MEMLCD_SPI_PERIPHERAL_NO              1

// USART1 TX on PC6
#define SL_MEMLCD_SPI_TX_PORT                    gpioPortC
#define SL_MEMLCD_SPI_TX_PIN                     6
#define SL_MEMLCD_SPI_TX_LOC                     11

// USART1 CLK on PC8
#define SL_MEMLCD_SPI_CLK_PORT                   gpioPortC
#define SL_MEMLCD_SPI_CLK_PIN                    8
#define SL_MEMLCD_SPI_CLK_LOC                    11
// [USART_SL_MEMLCD_SPI]$

// <gpio> SL_MEMLCD_SPI_CS
// $[GPIO_SL_MEMLCD_SPI_CS]
#define SL_MEMLCD_SPI_CS_PORT                    gpioPortD
#define SL_MEMLCD_SPI_CS_PIN                     14
// [GPIO_SL_MEMLCD_SPI_CS]$

// <gpio optional=true> SL_MEMLCD_EXTCOMIN
// $[GPIO_SL_MEMLCD_EXTCOMIN]
#define SL_MEMLCD_EXTCOMIN_PORT                  gpioPortD
#define SL_MEMLCD_EXTCOMIN_PIN                   13
// [GPIO_SL_MEMLCD_EXTCOMIN]$

// <<< sl:end pin_tool >>>

#else

// <<< sl:start pin_tool >>>
// <usart signal=TX,CLK> SL_MEMLCD_SPI
// $[USART_SL_MEMLCD_SPI]
#define SL_MEMLCD_SPI_PERIPHERAL                 USART1
#define SL_MEMLCD_SPI_PERIPHERAL_NO              1

// USART1 TX on PC6
#define SL_MEMLCD_SPI_TX_PORT                    gpioPortC
#define SL_MEMLCD_SPI_TX_PIN                     6
#define SL_MEMLCD_SPI_TX_LOC                     11

// USART1 CLK on PC8
#define SL_MEMLCD_SPI_CLK_PORT                   gpioPortC
#define SL_MEMLCD_SPI_CLK_PIN                    8
#define SL_MEMLCD_SPI_CLK_LOC                    11
// [USART_SL_MEMLCD_SPI]$

// <gpio> SL_MEMLCD_SPI_CS
// $[GPIO_SL_MEMLCD_SPI_CS]
#define SL_MEMLCD_SPI_CS_PORT                    gpioPortC
#define SL_MEMLCD_SPI_CS_PIN                     9
// [GPIO_SL_MEMLCD_SPI_CS]$

// <gpio optional=true> SL_MEMLCD_EXTCOMIN
// $[GPIO_SL_MEMLCD_EXTCOMIN]
#define SL_MEMLCD_EXTCOMIN_PORT                  gpioPortD
#define SL_MEMLCD_EXTCOMIN_PIN                   12
// [GPIO_SL_MEMLCD_EXTCOMIN]$

// <<< sl:end pin_tool >>>
#endif
#endif

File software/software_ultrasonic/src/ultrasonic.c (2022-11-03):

// Include logging for this file
#define INCLUDE_LOG_DEBUG 1
#include "src/log.h"

#include "app.h"

#include "src/ultrasonic.h"
#include "em_device.h"
#include "em_cmu.h"
#include "em_emu.h"
#include "em_gpio.h"
#include "em_leuart.h"
#include "em_chip.h"
#include "em_usart.h"
#include "timers.h"
#include "cbfifo.h"

extern cbfifo_t cbfifo_receive;


// Size of the buffer for received data
#define BUFLEN  80

// Receive data buffer
uint8_t buffer[BUFLEN];

// Current position ins buffer
uint32_t inpos = 0;
uint32_t outpos = 0;

// True while receiving data (waiting for CR or BUFLEN characters)
bool receive = true;

//static char txBuffer[RX_BUFFER_SIZE]; // Software transmit buffer

/**************************************************************************//**
 * @brief
 *    Initialize the GPIO pins for the LEUART module
 *****************************************************************************/
void initGpio(void)
{
  timerWaitUs_polled(1000000);
  // GPIO clock
  CMU_ClockEnable(cmuClock_GPIO, true);

  // Initialize LEUART0 TX and RX pins
//  GPIO_PinModeSet(gpioPortA, 3, gpioModePushPull, 1); // TX
  GPIO_PinModeSet(gpioPortA, 5, gpioModeInput, 0);    // RX

  //PA2: RX US1_RX #1
  //PA3: TX US1_TX #3

//  // Configure VCOM transmit pin to board controller as an output
//  GPIO_PinModeSet(BSP_BCC_TXPORT, BSP_BCC_TXPIN, gpioModePushPull, 1);
//
//  // Configure VCOM reeive pin from board controller as an input
//  GPIO_PinModeSet(BSP_BCC_RXPORT, BSP_BCC_RXPIN, gpioModeInput, 0);
//
//  // Enable VCOM connection to board controller
//  GPIO_PinModeSet(BSP_BCC_ENABLE_PORT, BSP_BCC_ENABLE_PIN, gpioModePushPull, 1);
}

/**************************************************************************//**
 * @brief
 *    Initialize the LEUART module
 *****************************************************************************/
void initUsart2(void)
{

  //PA2: RX US1_RX #1
    //PA3: TX US1_TX #3

  //PA5: RX US2_RX #31

  // Enable clocks for LEUART0
  CMU_ClockEnable(cmuClock_USART2, true);
//  CMU_ClockDivSet(cmuClock_USART1, cmuClkDiv_1); // Don't prescale LEUART clock

  //Initialize the USART1 module

  USART_InitAsync_TypeDef init = {                                                                   \
      usartEnable,           /* Enable RX/TX when initialization is complete. */                     \
      0,                     /* Use current configured reference clock for configuring baud rate. */ \
      9600,                /* 9600 bits/s. */                                                    \
      usartOVS4,            /* 16x oversampling. */                                                 \
      usartDatabits8,        /* 8 data bits. */                                                      \
      usartNoParity,         /* No parity. */                                                        \
      usartStopbits1,        /* 1 stop bit. */                                                       \
      false,                 /* Do not disable majority vote. */                                     \
      false,                 /* Not USART PRS input mode. */                                         \
      0,                     /* PRS channel 0. */                                                    \
      false,                 /* Auto CS functionality enable/disable switch */                       \
      0,                     /* Auto CS Hold cycles */                                               \
      0,                     /* Auto CS Setup cycles */                                              \
      usartHwFlowControlNone /* No HW flow control */                                                \
    };



  // Configure and enable USART1
  USART_InitAsync(USART2, &init);

  // Enable NVIC USART sources
  NVIC_ClearPendingIRQ(USART2_RX_IRQn);
  NVIC_EnableIRQ(USART2_RX_IRQn);
//  NVIC_ClearPendingIRQ(USART2_TX_IRQn);
//  NVIC_EnableIRQ(USART2_TX_IRQn);

  // Enable RX and TX for USART1 VCOM connection
  USART2->ROUTELOC0 = /*USART_ROUTELOC0_TXLOC_LOC3 | */USART_ROUTELOC0_RXLOC_LOC31;
  USART2->ROUTEPEN |= USART_ROUTEPEN_RXPEN/* | USART_ROUTEPEN_TXPEN*/;
  USART2->CTRL |= USART_CTRL_RXINV;

  USART_IntEnable(USART2, USART_IEN_RXDATAV);
  LOG_INFO("Finished setting up usart2\n\r");


  /*
   *
   *

  // Default asynchronous initializer (115.2 Kbps, 8N1, no flow control)
  USART_InitAsync_TypeDef init = USART_INITASYNC_DEFAULT;

  // Configure and enable USART0
  USART_InitAsync(USART0, &init);

  // Enable NVIC USART sources
  NVIC_ClearPendingIRQ(USART0_RX_IRQn);
  NVIC_EnableIRQ(USART0_RX_IRQn);
  NVIC_ClearPendingIRQ(USART0_TX_IRQn);
  NVIC_EnableIRQ(USART0_TX_IRQn);

  // Enable RX and TX for USART0 VCOM connection
  USART0->ROUTELOC0 = BSP_BCC_RX_LOCATION | BSP_BCC_TX_LOCATION;
  USART0->ROUTEPEN |= USART_ROUTEPEN_RXPEN | USART_ROUTEPEN_TXPEN;
   */
}


/*----------------------------------------------------------------------------
 * Standard system I/O function
 ----------------------------------------------------------------------------*/
int get_received_char_usart2(void)
{
  int c;

  //returns -1 to indicate that no new char has received
  if(cbfifo_length(&cbfifo_receive) < 1)
  {
    return -1;
  }
  else
  {
    //Entering critical section
      // enter critical section
    CORE_DECLARE_IRQ_STATE;
    CORE_ENTER_CRITICAL();
    cbfifo_dequeue(&cbfifo_receive, &c, sizeof(c));
    CORE_EXIT_CRITICAL();
    return c;
  }
}



/*----------------------------------------------------------------------------
 * Standard system I/O function
 ----------------------------------------------------------------------------*/
int get_processed_data_from_ultrasonic_sensor(void)
{
  char c;
  c = get_received_char_usart2();
  static uint8_t multiplier;
  static uint8_t distance;

  switch(c)
  {
    case -1:
      break;

    case '\r':
      distance = 0;
      multiplier = 1;
      break;

    case 'R':
      multiplier = 0;
      return distance;
      break;

    default:
      distance += multiplier * (c - '0');
      multiplier = multiplier*10;
      break;
  }
  return 0;
}
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

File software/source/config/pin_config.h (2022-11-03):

#ifndef PIN_CONFIG_H
#define PIN_CONFIG_H

// $[ACMP0]
// [ACMP0]$

// $[ACMP1]
// [ACMP1]$

// $[ADC0]
// [ADC0]$

// $[CMU]
// [CMU]$

// $[DBG]
// DBG SWCLKTCK on PF0
#define DBG_SWCLKTCK_PORT                        gpioPortF
#define DBG_SWCLKTCK_PIN                         0
#define DBG_ROUTE_LOC                            0

// DBG SWDIOTMS on PF1
#define DBG_SWDIOTMS_PORT                        gpioPortF
#define DBG_SWDIOTMS_PIN                         1

// DBG TDO on PF2
#define DBG_TDO_PORT                             gpioPortF
#define DBG_TDO_PIN                              2

// [DBG]$

// $[ETM]
// [ETM]$

// $[PTI]
// [PTI]$

// $[GPIO]
// [GPIO]$

// $[I2C0]
// I2C0 SCL on PC11
#define I2C0_SCL_PORT                            gpioPortC
#define I2C0_SCL_PIN                             11
#define I2C0_SCL_LOC                             15

// I2C0 SDA on PC10
#define I2C0_SDA_PORT                            gpioPortC
#define I2C0_SDA_PIN                             10
#define I2C0_SDA_LOC                             15

// [I2C0]$

// $[I2C1]
// [I2C1]$

// $[LESENSE]
// [LESENSE]$

// $[LETIMER0]
// [LETIMER0]$

// $[LEUART0]
// [LEUART0]$

// $[LFXO]
// LFXO N on PB14
#define LFXO_N_PORT                              gpioPortB
#define LFXO_N_PIN                               14

// LFXO P on PB15
#define LFXO_P_PORT                              gpioPortB
#define LFXO_P_PIN                               15

// [LFXO]$

// $[MODEM]
// [MODEM]$

// $[PCNT0]
// [PCNT0]$

// $[PRS.CH0]
// [PRS.CH0]$

// $[PRS.CH1]
// [PRS.CH1]$

// $[PRS.CH2]
// [PRS.CH2]$

// $[PRS.CH3]
// [PRS.CH3]$

// $[PRS.CH4]
// [PRS.CH4]$

// $[PRS.CH5]
// [PRS.CH5]$

// $[PRS.CH6]
// [PRS.CH6]$

// $[PRS.CH7]
// [PRS.CH7]$

// $[PRS.CH8]
// [PRS.CH8]$

// $[PRS.CH9]
// [PRS.CH9]$

// $[PRS.CH10]
// [PRS.CH10]$

// $[PRS.CH11]
// [PRS.CH11]$

// $[TIMER0]
// [TIMER0]$

// $[TIMER1]
// [TIMER1]$

// $[USART0]
// USART0 RX on PF3
#define USART0_RX_PORT                           gpioPortF
#define USART0_RX_PIN                            3
#define USART0_RX_LOC                            26

// USART0 TX on PF4
#define USART0_TX_PORT                           gpioPortF
#define USART0_TX_PIN                            4
#define USART0_TX_LOC                            28

// [USART0]$

// $[USART1]
// USART1 CLK on PC8
#define USART1_CLK_PORT                          gpioPortC
#define USART1_CLK_PIN                           8
#define USART1_CLK_LOC                           11

// USART1 RX on PC7
#define USART1_RX_PORT                           gpioPortC
#define USART1_RX_PIN                            7
#define USART1_RX_LOC                            11

// USART1 TX on PC6
#define USART1_TX_PORT                           gpioPortC
#define USART1_TX_PIN                            6
#define USART1_TX_LOC                            11

// [USART1]$

// $[USART2]
// [USART2]$

// $[VDAC0]
// [VDAC0]$

// $[WTIMER0]
// [WTIMER0]$

#endif // PIN_CONFIG_H
